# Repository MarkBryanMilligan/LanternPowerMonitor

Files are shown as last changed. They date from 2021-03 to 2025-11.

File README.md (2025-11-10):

# LanternPowerMonitor
The Lantern Power Monitor is a Raspberry Pi service, Java Web Service, and Android application that allow you to monitor every electrical breaker in your house, regardless of how many panels or breakers you have.
<br><br>
The official website has a lot of technical information:
<br>
[LanternPowerMonitor.com](https://lanternpowermonitor.com)
<br><br>
Here's an imgur album showing what this is and how it works:
<br>
[Lantern Power Monitor - Imgur](https://imgur.com/gallery/SPOJYBR)
<br><br>
The android application is available here:
<br>
[Lantern Power Monitor - Google Play](https://play.google.com/store/apps/details?id=com.lanternsoftware.lantern)
<br><br>
The iOS application is available here:
<br>
[Lantern Power Monitor - App Store](https://apps.apple.com/us/app/lantern-power-monitor/id1620735464)
<br><br>
The LanternPowerMonitor subreddit is a great place to ask questions and stay tuned for updates and news.
<br>
[/r/LanternPowerMonitor](https://www.reddit.com/r/LanternPowerMonitor/)
<br><br>

You can use the bom in the source below to buy the parts to build a hub.

# Index
## bom
An excel file that lists every part required to construct a Lantern Power Monitor Hub and links to where each part can be purchased.<br>

## case
STL files and Blender models to print your own case for a Lantern Power Monitor Hub
## java
Contains all source code for the raspberry pi service and the web service.  The raspberry-pi service posts data to the web service which also handles requests for data from the android app.
#### lantern-powermonitor
This is the raspberry pi service.
#### lantern-powermonitor-dataaccess
A mongodb implementation of the data access for the power monitor service.
#### lantern-powermonitor-datamodel
A shared data model used by the raspberry pi service, the web service, and the android application.
#### lantern-powermonitor-service
This is the web service (compiles to a war and can most easily be deployed to tomcat)
## lantern-util-*
Utility libraries used by the raspberry pi service, the web service, and the android application.
## lantern-zwave-*
These are only tangentially related.  These are libraries for running a zwave controller and a web service that the android app can use to control zwave devices and relays in your home.  This isn't currently part of the provided sd image, but I use it in my home to control our garage doors, compressors, lights, thermostats, thermometers, and all sorts of other fun stuff.
## pcb
Gerber files and the source EasyEDA file for the Lantern Power Monitor Hub v1 pcb.

# Ok, how do I run this thing?
The easiest way to run the software on a hub is to download a pre-built SD card image.  One can be downloaded here:<br>
[2.0.0.img.gz](https://lanternpowermonitor.com/images/2.0.0.img.gz)
<br><br>
Flash this to any micro sd card (4gig or larger) and you're good to go.  Fire up the hub and the phone app should be able to connect to it via bluetooth to finish the configuration.  The default password on this image is pi/LanternPowerMonitor<br><br>
When you add the hub to your configuration via the app, you can change where the hub posts data.  If you use lanternpowermonitor.com (the default host), your data will be stored there securely and won't be shared with or sold to anyone.  If you really want to run your own server, you're of course welcome to do that instead, instructions are located further down.

## Now that the service is running on the pi, how do I configure everything in the android app?
1. Create your panel in the "Configure Panels" page from the main menu. Before you have your hub connected, there will be no place to select a hub and port for each breaker. Don't worry, we'll get to that later.

1. With your hub plugged in and running for at least a minute, go into the "Configure Hubs" page from the main menu. In here you'll see a status of "Scanning for Hubs..." If you're in range of your hub and its service is running, the app should find it pretty quickly (less than 15 seconds). If this is the first hub you've added, it will prompt you for your wifi credentials. After that, it will send via bluetooth the hub index (so it knows which hub it is), host (so it knows where to post data), auth code (so it knows which account it is and can post data), the encrypted wifi credentials, and finally a command to reboot.

1. After your hub reboots, it should acquire an ip from your router, start the service, and try to start posting data. The hubs will try to auto-calibrate your voltage to 120V too, but if your AC/AC transformer is not plugged in, it will notice that and not try to auto-calibrate. It will continue to try to auto-calibrate each time you restart the hub until it does so succesfully.

1. Now that your hub is in the app, you need to go back into your panel and map each space to the port that you plugged the CT into. So say you put a CT on space 4, and you plugged that CT into port 7 on your hub, in your panel config, select space 4 and at the bottom, select hub 0 and port 7.

1. After you have your ports mapped, the hub does not currently pick up that change automatically. I will make it do that eventually, but for right now, you need to restart your hub one more time. (You can do this via bluetooth, but it's probably easier to just yank the power and plug it back in)

1. After that second restart, you should start seeing data. If you're not getting data in your app, the hub probably was not able to get a wifi connection. You can pull the last 10 lines of the log file and network details from the hub via bluetooth on the hub config page to troubleshoot.

# Ok, but I don't like doing things the easy way.
First, you and I will get along just fine.  Second, do a reactor build from the root folder:
```
~/LanternPowerMonitor/java$ gradlew clean build publishToMavenLocal
```
## raspberry pi service
The compiled service will be at LanternPowerMonitor/powermonitor/lantern-powermonitor/target/lantern-powermonitor.jar<br>
This is a shaded jar that contains all of the required components to function.  It must be copied to /opt/powermonitor on the pi.<br><br>

After that, you need to install pigpio:
```
sudo apt-get install pigpio
```
You also need to have java 1.8 or newer installed.
To install the power monitor service, use a service file like the one below:
```
[Unit]
Description=Power Monitor
After=syslog.target network-online.target
Wants=network-online.target

[Service]
Type=simple

User=root
Group=root

WorkingDirectory=/opt/powermonitor

ExecStart=/opt/java/bin/java -cp /opt/powermonitor/lantern-powermonitor.jar com.lanternsoftware.powermonitor.MonitorApp

[Install]
WantedBy=multi-user.target
```
You may need to change the path of your jdk, but lantern-powermonitor.jar must be installed at /opt/powermonitor<br>
Move your powermonitor.service file to /etc/systemd/system/ and enable the service
```
sudo mv powermonitor.service /etc/systemd/system/
sudo systemctl enable powermonitor
```
## web service
So you don't trust me with your data, eh?  No worries, I get it.  Here's how you run your own server.<br><br>
After your reactor build, the compiled war will be at LanternPowerMonitor/java/lantern-powermonitor-service/build/libs/lantern-powermonitor-service-2.x.x.war
That can be deployed to tomcat.  The 'host' parameter in the raspberry pi config.json file needs to point to wherever you deploy the service so your hubs post the data to your server instead of the official lantern software one.<br>
I'd recommend a valid dns entry and an ssl certificate, but, it's up to you, you're already knee deep in "I'll do what I want" territory here.<br><br>
Before you deploy it, you need to generate a config file that contains the mongodb credentials.<br>
There is a file at lantern-powermonitor-config/src/main/java/com/lanternsoftware/powermonitor/CreateMongoConfig.java that can do this for you.<br>
Place the generated config file in /opt/tomcat (which is where I have tomcat installed).  If you want it to be read from somewhere else, you can modify the paths in LanternFiles.java<br><br>
The last thing you need is a private aes key to encrypt user auth tokens.  One of those can be generated with CreateAuthKey.java.<br>
I realize these instructions aren't complete, but if you're going down this path, I suspect you sort of already know what you're doing, so hopefully that's enough to point you in the right direction.

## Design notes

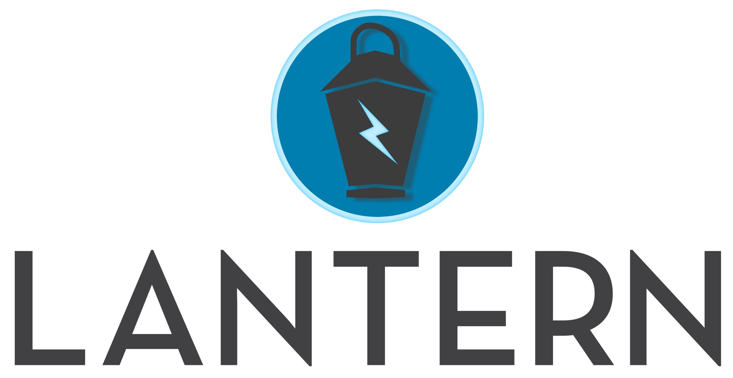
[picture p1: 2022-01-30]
java/lantern-powermonitor-service/src/main/webapp/img/lantern_cm.png

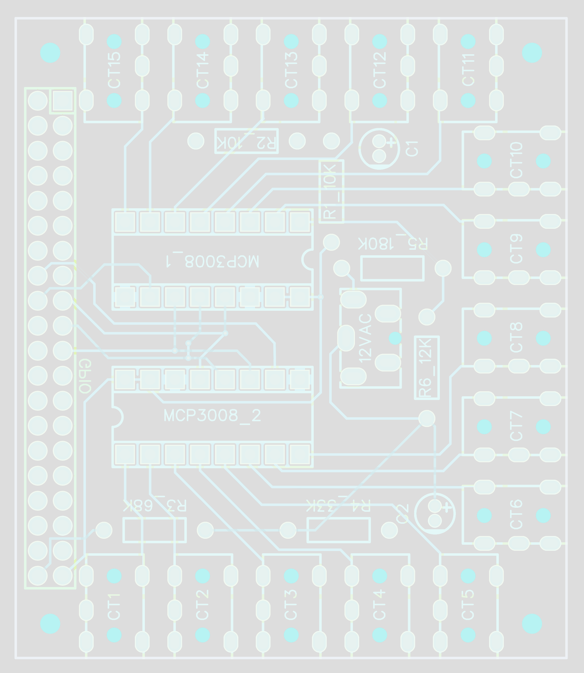
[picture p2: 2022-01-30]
java/lantern-powermonitor-service/src/main/webapp/img/pcb.png

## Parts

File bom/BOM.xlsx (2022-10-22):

Item Name | Part Number | URL | Quantity Required
Lantern Power Monitor Case | LPMC1 | https://github.com/MarkBryanMilligan/LanternPowerMonitor/tree/main/case | 1
Lantern Power Monitor Case Lid | LPMCL1 | https://github.com/MarkBryanMilligan/LanternPowerMonitor/tree/main/case | 1
Lantern Power Monitor Soldering Jig | LPMSJ1 | https://github.com/MarkBryanMilligan/LanternPowerMonitor/tree/main/case | 1
Lantern Power Monitor PCB | LPMPCB1 | https://github.com/MarkBryanMilligan/LanternPowerMonitor/tree/main/pcb | 1
Raspberry Pi 3 Model A+ | 3A+ | https://www.raspberrypi.org/products/raspberry-pi-3-model-a-plus/ | 1
Jameco 12V AC/AC Adapter | 10428 | https://www.jameco.com/z/ACU120100Z9121-Jameco-Reliapro-AC-to-AC-Wall-Adapter-Transformer-12-Volt-AC-1000mA-Black-Straight-3-5mm-Male-Plug_10428.html | 1
16gb memory card | P-SDU16GU185GW-GE | https://www.microcenter.com/product/486146/micro-center-16gb-microsdhc-class-10-flash-memory-card | 1
40-pin GPIO header | C169819 | https://lcsc.com/product-detail/Pin-Header-Female-Header_Ckmtw-Shenzhen-Cankemeng-C169819_C169819.html | 1
MCP3008 | MCP3008-I-P | https://www.digikey.com/en/products/detail/microchip-technology/MCP3008-I-P/319422 | 2
10uF 25V 4*5 Capacitor | C43846 | https://lcsc.com/product-detail/Aluminum-Electrolytic-Capacitors-Leaded_CX-Dongguan-Chengxing-Elec-10uF-25V-4-5_C43846.html | 1
22uF 25V 4*7 Capacitor | C43840 | https://lcsc.com/product-detail/Aluminum-Electrolytic-Capacitors-Leaded_CX-Dongguan-Chengxing-Elec-22uF-25V-4-7_C43840.html | 1
10KΩ Resistor | C385441 | https://lcsc.com/product-detail/Metal-Film-Resistor-TH_TyoHM-RN1-2WS10K%CE%A9FT-BA1_C385441.html | 2
12KΩ Resistor | C385449 | https://lcsc.com/product-detail/Metal-Film-Resistor-TH_TyoHM-RN1-2WS12K%CE%A9FT-BA1_C385449.html | 1
180KΩ Resistor | C385460 | https://lcsc.com/product-detail/Metal-Film-Resistor-TH_TyoHM-RN1-2WS180K%CE%A9FT-BA1_C385460.html | 1
33KΩ Resistor | C385498 | https://lcsc.com/product-detail/Metal-Film-Resistor-TH_TyoHM-RN1-2WS33K%CE%A9FT-BA1_C385498.html | 1
68KΩ Resistor | C433508 | https://lcsc.com/product-detail/Metal-Film-Resistor-TH_TyoHM-RN1-2WS68K%CE%A9FT-BA1_C385541.html | 1
3.5mm Headphone Jack | C397337 | https://lcsc.com/product-detail/Audio-Video-Connectors_XKB-Enterprise-PJ-3583-B_C397337.html | 16
M2.5x10mm Cap Screw | A15120300ux0225 | https://www.amazon.com/gp/product/B01B1OD7IK | 8
M2.5x11mm Female x Female Standoff |  | https://www.ebay.com/itm/50pcs-M2-5-Female-Hex-Screw-Brass-PCB-Standoffs-Hexagonal-Spacers/172746413434 | 4
M2.5x12mm Female x Male Standoff |  | https://www.ebay.com/itm/M2-5-2-5mm-Thread-6mm-Brass-Standoff-Spacer-Male-x-Female-20-50pcs-New/283432513974 | 4
50 Amp Current Transformer | SCT-013-050 | N/A
30 Amp Current Transformer | SCT-013-030 | N/A
20 Amp Current Transformer | SCT-013-020 | N/A

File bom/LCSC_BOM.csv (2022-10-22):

LCSC Part Number | Quantity
C2977589 | 1
C43846 | 1
C43840 | 1
C385441 | 2
C385449 | 1
C385460 | 1
C385498 | 1
C433508 | 1
C397337 | 16

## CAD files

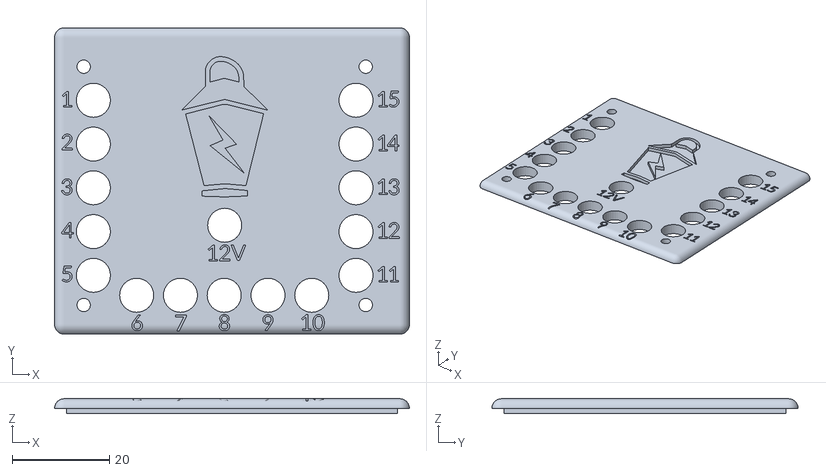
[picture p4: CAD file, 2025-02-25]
case/3A+/LPM_Case_Lid_3A+.stl
73.0 x 63.0 x 3.00

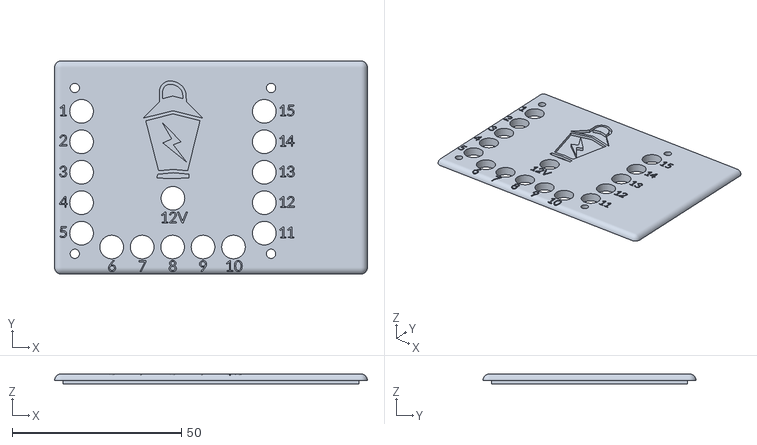
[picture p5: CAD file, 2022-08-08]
case/3B+/LPM_Case_Lid_3B+.stl
92.5 x 63.0 x 3.00

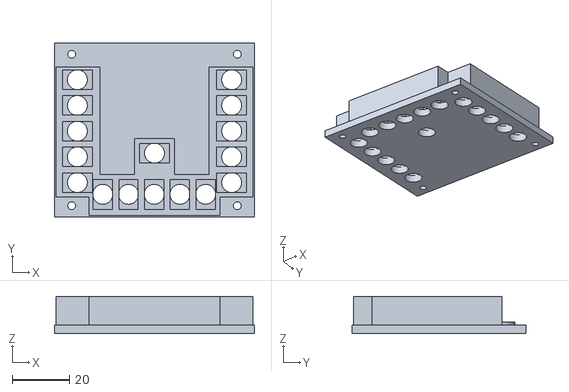
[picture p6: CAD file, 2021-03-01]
case/LPM_Soldering_Jig.stl
70.0 x 61.0 x 13.0

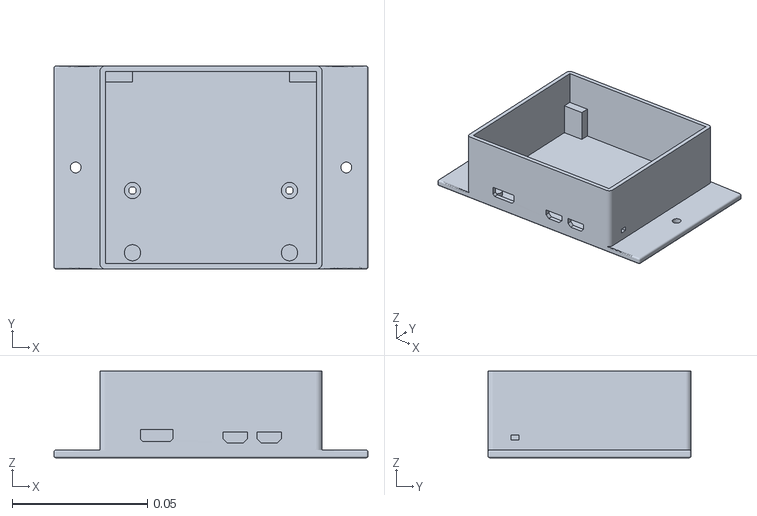
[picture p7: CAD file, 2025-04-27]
case/Z2/LPM30_Case_Z2_Base_Flange.stl
0.116 x 0.075 x 0.032

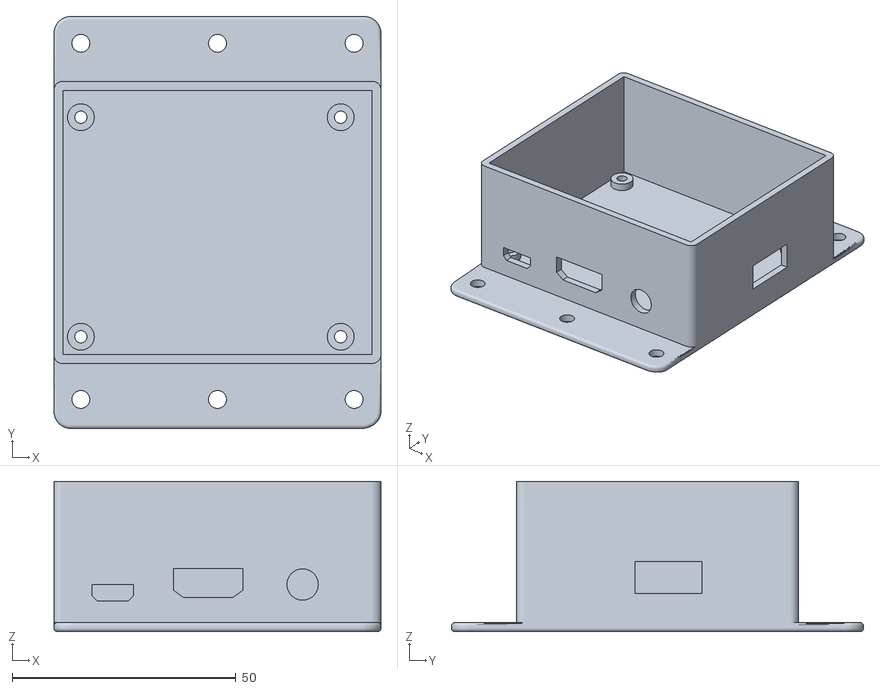
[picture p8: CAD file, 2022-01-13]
case/3A+/LPM_Case_Flange_3A+.stl
73.0 x 92.0 x 33.5

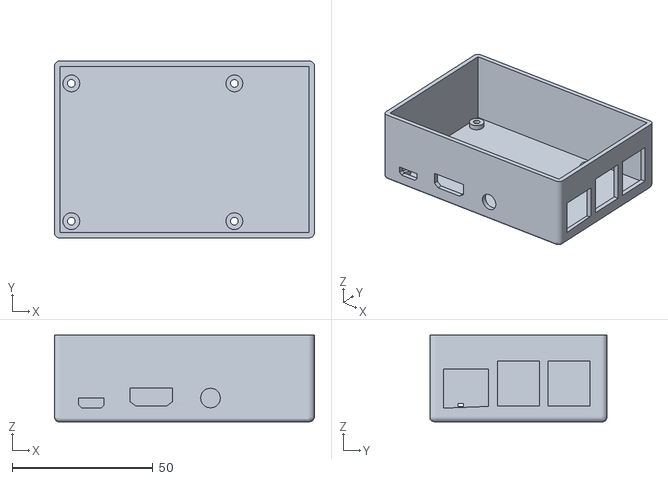
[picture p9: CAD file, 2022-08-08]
case/3B+/LPM_Case_3B+.stl
92.5 x 63.0 x 30.9

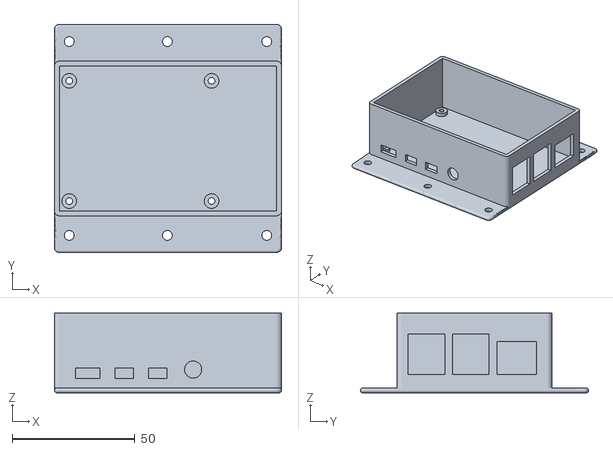
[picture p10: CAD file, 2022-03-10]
case/4B/LPM_Case_Flange_4B.stl
92.5 x 93.0 x 32.5

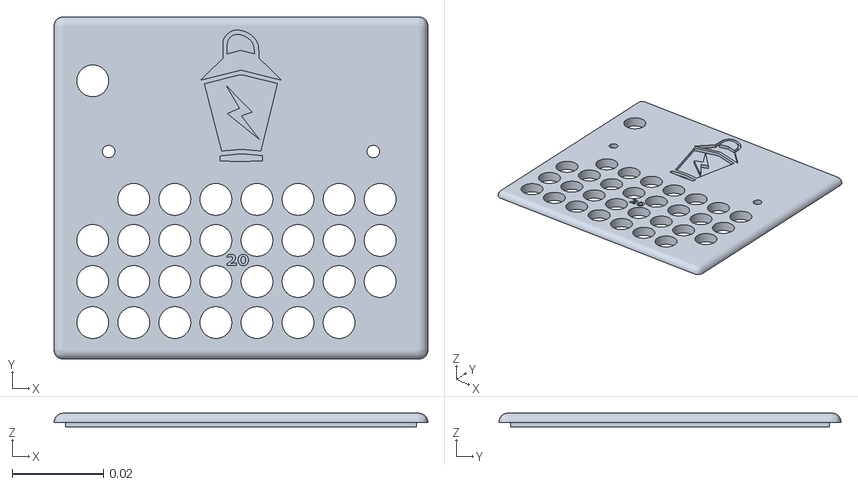
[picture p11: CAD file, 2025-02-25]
case/Z2/LPM30_Z2_Text_Lid.stl
0.082 x 0.075 x 0.003

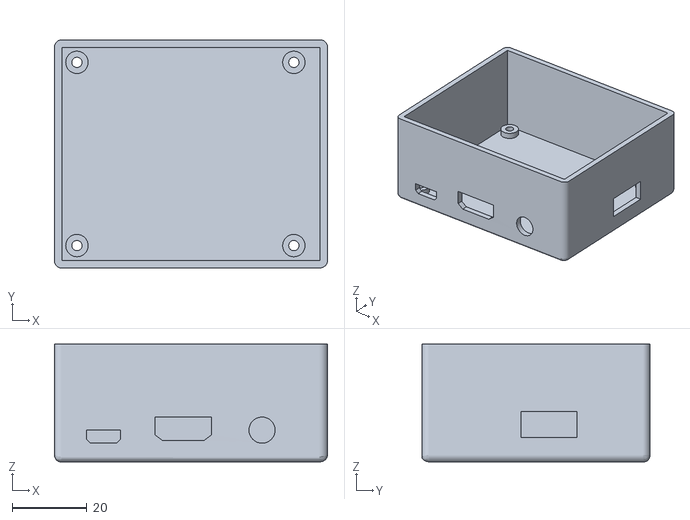
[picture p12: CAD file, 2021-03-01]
case/3A+/LPM_Case_3A+.stl
73.0 x 61.0 x 31.5

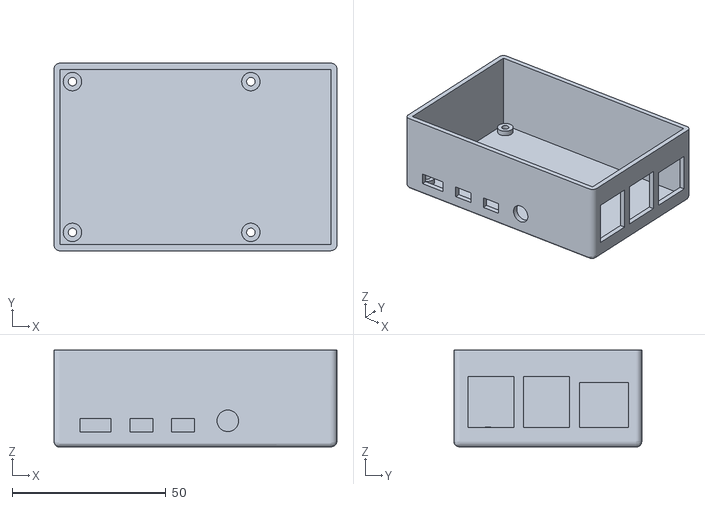
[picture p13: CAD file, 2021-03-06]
case/4B/LPM_Case_4B.stl
92.0 x 61.0 x 31.5

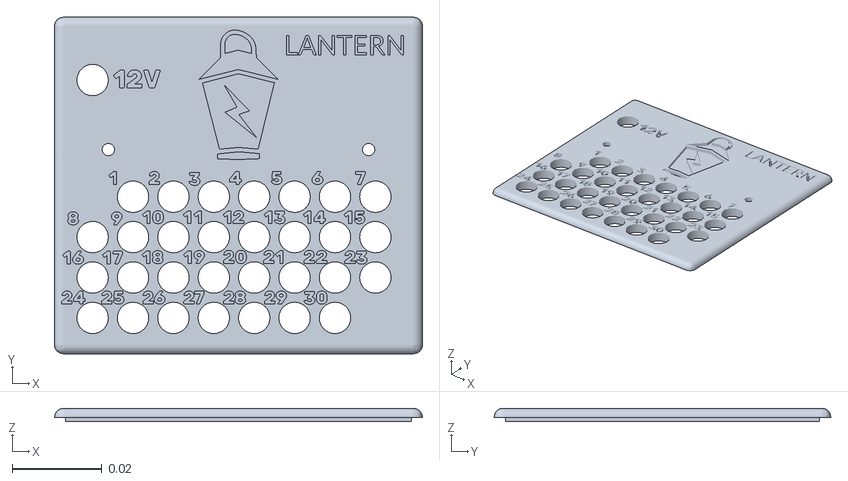
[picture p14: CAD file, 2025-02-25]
case/Z2/LPM30_Z2_Lid_Labeled.stl
0.082 x 0.075 x 0.003

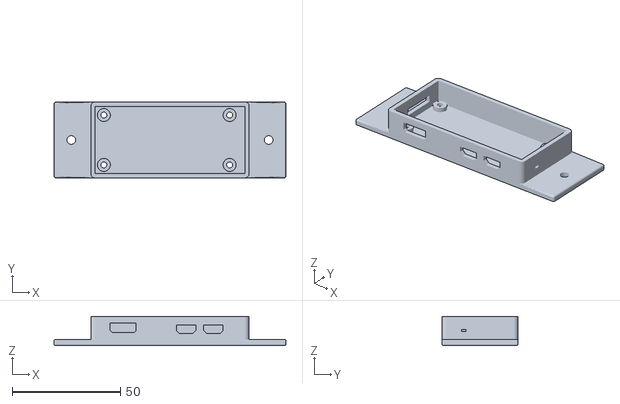
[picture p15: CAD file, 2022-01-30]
case/Z2/LPM_Case_Z2_Base_Flange.stl
107.0 x 35.0 x 13.5

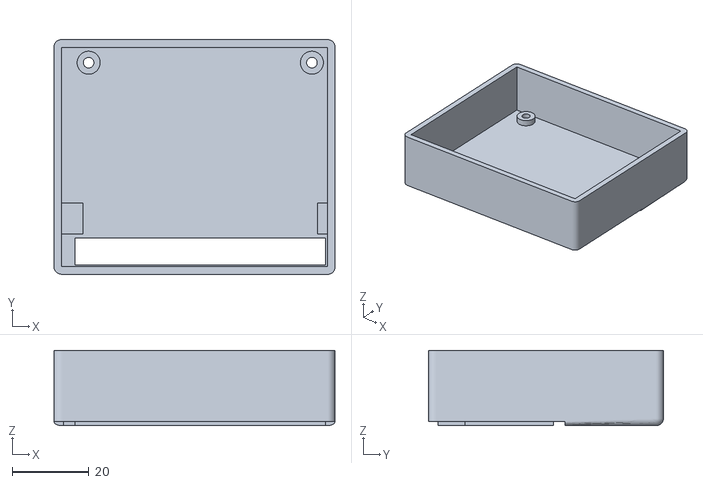
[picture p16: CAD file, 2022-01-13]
case/Z2/LPM_Case_Z2_Middle.stl
73.0 x 61.0 x 19.5

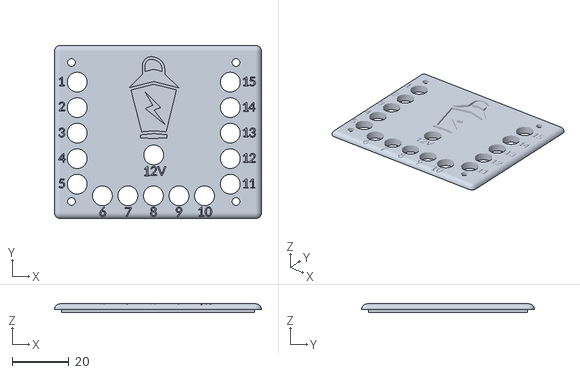
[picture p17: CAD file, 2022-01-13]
case/Z2/LPM_Case_Z2_Lid.stl
73.0 x 61.0 x 3.00

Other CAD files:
case/4B/LPM_Case_Lid_4B.stl
case/3B+/LPM_Case_Flange_3B+.stl
case/Z2/LPM30_Case_Z2_Lid.stl
case/Z2/LPM_Case_Z2_Base.stl
case/3A+/LPM_Case_3A+.blend
case/3A+/LPM_Case_Flange_3A+.blend
case/3A+/LPM_Case_Lid_3A+.blend
case/3B+/LPM_Case_3B+.blend
case/3B+/LPM_Case_Flange_3B+.blend
case/3B+/LPM_Case_Lid_3B+.blend
case/4B/LPM_Case_4B.blend
case/4B/LPM_Case_Flange_4B.blend
case/4B/LPM_Case_Lid_4B.blend
case/LPM_Soldering_Jig.blend
case/Z2/LPM30_Case_Z2_Base_Flange.blend
case/Z2/LPM30_Case_Z2_Lid.blend
case/Z2/LPM30_Case_Z2_Lid_Labeled.blend
case/Z2/LPM30_Case_Z2_Lid_text.blend
case/Z2/LPM_Case_Z2_Base.blend
case/Z2/LPM_Case_Z2_Base_Flange.blend
case/Z2/LPM_Case_Z2_Lid.blend
case/Z2/LPM_Case_Z2_Middle.blend
case/Z2/Z2_GPIO_Lid.blend
case/Z2/Z2_GPIO_Lid.stl
case/logo.blend

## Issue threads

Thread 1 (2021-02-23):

Track 240V double breaker with one CT

MarkBryanMilligan, 2021-02-23:
Right now, each pole of a double pole breaker requires its own CT.  To save on the cost of current transformers, add a configuration variable so only the top breaker needs a CT and the power of the top pole is doubled in software.

JamesAndrews352, 2021-02-23:
That would save some hardware for sure. Keep in mind some 240v loads may have a neutral and 120v loads like a stove/range, but yeah, most are balanced. I have a 30 space panel with 1 tandem breaker, so I like the idea. Save me from a third meter. Love your work!!

MarkBryanMilligan, 2021-02-23:
Ok, thanks for that info.  That's why I decided to track both for now just to make sure it was accurate, I had a feeling some appliances might have unbalanced usage.  None of mine do, but it's good to know that it's a possible use case.  I think I'll make this a configuration option for the double breaker so those who need to track both poles individually will still be able to.

dcsar1, 2021-02-23:
Another vote for this one.  I just ordered a couple of kits.  When the canoe from China (with the sensors) finally makes landfall I hope to set this up.

MarkBryanMilligan, 2021-02-23:
It's kinda lame that GitHub doesn't have a voting system for issues.  What could that take to add, like an afternoon??  I always add a comment when adding an issue (and I would expect anyone else creating an issue to do the same).  I think we should use a thumbs up on that first description comment to count as a vote.  Then I should be able to visualize a little more easily what to do first.

MarkBryanMilligan, 2021-02-26:
Ok, this one is done:
[Commit](https://github.com/MarkBryanMilligan/LanternPowerMonitor/commit/a75231dc437cc4e1e5b87e6aec084bac215a0ebe)

I'll leave this issue open until someone else verifies that it works, but I just tried it in my house on our heat pump and it seems to be working fine.  I'll push a new release to google play for the app, it should be available tomorrow.

In the panel config, you can now select "Double Pole (240V) Two CTs" or "Double Pole (240V) One CT Doubled"

MarkBryanMilligan, 2021-02-28:
I saw when I close the other issue that I can reopen them if there ends up being a problem.  This change has been working fine in my has for the past couple days so I'm gonna go ahead and close the issue.

Closed 2021-02-28.

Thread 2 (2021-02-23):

Allow tracking mains power in addition to individual breakers

MarkBryanMilligan, 2021-02-23:

kitlaan, 2021-12-26:
I noticed there is no 200A CT available in the 0-1V configuration. Does that put a limit to this feature?

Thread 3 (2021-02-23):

Create Raspberry Pi 4 image

MarkBryanMilligan, 2021-02-23:
The current image only seems to work on a Pi 3 out of the box.  It can be made to work on the Pi 4 but you need to tweak some stuff on the command line.  It'd be easier for Pi 4 users to have an image that works without any modification.

rharter, 2021-02-23:
Curious if there's any reason this can't work on a Zero.  The Zero W has a 40 pin header (no stock connector), and seems comparably speced to the 3A. And...it's $10. Event better, the original Zero 1.3 is $5 at [Adafruit](https://www.adafruit.com/product/2885), which is really attractive for something like this, which doesn't need USB hubs and HDMI ports.

MarkBryanMilligan, 2021-02-23:
I kind of expect it to be CPU limited.  On a pi 3 A+ (or B+) with the quad core Cortex-A53 1.4 GHz, it gets about 300 samples per cycle.  On a 4 b+ with its quad core Cortex-A72 1.5 GHz, it gets about 400 samples per cycle.  A zero only has a single core and I keep one core pegged at 100% cpu 24/7 sampling the ADCs.  I thread off calculating the power and posting it to the server since there are other cores available for that work.  I have a feeling on a single core machine running java, the sampling would get all jacked up as garbage collection occurs during the computation and http call phase of each second.

MarkBryanMilligan, 2021-02-28:
I made a new image that works on both pi 3s and pi 4s.  I also zipped it this time to make the download smaller.  The new image is [here](https://lanternsoftware.com:13781/hub_1.0.0.zip)

Closing this issue.

Closed 2021-02-28.

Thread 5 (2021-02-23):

Allow configuration of non-US systems

MarkBryanMilligan, 2021-02-23:
Right now the app assumes 60Hz 120V.  The data model, hubs, and server support other frequencies and voltages, but there's no place to set them in the app.  Once I add a meter page, this should go there.

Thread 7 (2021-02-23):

Get the Android code posted to GitHub.

MarkBryanMilligan, 2021-02-23:
I need to externalize some secrets from the app before I post it to GitHub.  There's also a whole other half of the app for controlling z-wave devices and reading usb thermometers that really only works for my house right now.  That other half of the app is just turned off unless you set the host to the server at my house here.  I need to get that cleaned up before I post the code so people don't start turning my lights on and off and hotboxing my family in the middle of the night.

phinze, 2022-03-19:
Hi @MarkBryanMilligan! My power monitor is arrived and physically installed, but it was only at that point that I realized that I don't have any Android devices handy outside of an old TV remote (Vizio XR6M10). Unfortunately this device is stuck on Marshmallow which won't install the app from the Play store. I was wondering if that minimum Android version constraint was something that could be easily tweaked, which brought me here. I'd be happy to take a look at this myself if you can push the code.

Ultimately though I'm going to be more interested in the iOS platform, so I'd love to hear any update on where things are at on that front. Regardless, I'm excited to chip in a bit and get things cooking w/ my monitor! :)

MarkBryanMilligan, 2022-03-19:
The minimum is Android 7.1 because Android made a huge non-passive change to the way the bluetooth platform works on that version.  Making bluetooth work on an older version of Android would be a ton of work and I'd rather spend that time on iOS.

If you feel like a project, you could root your Vizio tablet and install LineageOS on it.  I did that with my 10 year old Nexus 7 tablet and it works great with the app now.  A quick google search for "Vizio XR6M10 LineageOS" can probably get you started (again, at your own risk, legality and safety not guaranteed :) )

I'm back to working on the iOS app.  I have the data rendering in the graphs ok, but I need to do all of the configuration pages and the bluetooth stuff.  It's at least a couple months of work.  I'm developing on a 2012 Mac Mini right now and it's crazy slow.  I finished shipping out all of the Kickstarter rewards this past week (except for those who haven't responded to my survey), so I need to double check how much money is left from the Kickstarter.  If I have enough I want to get a new M1 Mac Mini to speed up the iOS development.

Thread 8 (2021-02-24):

Add "Sense" like capability per circuit

JamesAndrews352, 2021-02-24:
While most loads are obvious, for example, the water heater is the only load on the water heater breaker. A kitchen may have a dishwasher, microwave, and garbage disposal on the same circuit. I'm not proposing some fancy artificial Intelligence, just the ability to turn on an appliance and have the system recognize that specific load, then it would be broken out under that circuit so you know how much each appliance uses. Maybe more complicated than I think.

MarkBryanMilligan, 2021-02-24:
Yeah, I could see the use for an intermediate mode, not really what sense does.  So like you just manually figure out what each device uses by watching the instantaneous power while you turn it on and off.  Oh, ok, my microwave uses 1300 watts.  Now I'll configure a watch item for this breaker, if the power jumps between 1200 and 1400 up or down, well then that's the microwave turning on or off.  Basically manually train it for each thing.  Then you add in some extra logic in the summary aggregation that watches for those changes and puts the power in a subgroup when the state changes.  I bet that's about a week project.

kitlaan, 2021-12-26:
I ran across the [NILMTK](https://github.com/nilmtk/nilmtk) while googling around, which seems to be research around this area.  It's all voodoo to me so maybe someone else can determine what's required to utilize it.

At the very least, a way to store/export data in HDF5 format may be useful to help the community and/or allow external integrations?  (Aside, the data storage requirement is probably high, so storing on a SD card seems unwise? USB storage? NAS?)

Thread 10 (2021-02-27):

Modify the case for the pi 3A+ to have mounting tabs

MarkBryanMilligan, 2021-02-27:
The current case can only rest on something.  There needs to be a version of it with tabs on the side with holes that a screw could be put through for wall mounting.

JamesAndrews352, 2021-02-28:
I like that the case is so small, but I can see where some may want to screw it to something. Since it will have to be raised to clear the screw heads, It will require support while printing. Probably easiest solution is make the bottom thicker with the added material extending past the ends and recess the screws. I'll look at it.

JamesAndrews352, 2021-02-28:
I have a revised box with flange but don't know how to upload it

JamesAndrews352, 2021-03-01:
You can view it on my google drive. I re scaled the other files as well so they should print. Let me know if you hate it or want to change something. I put the flange on the long side since you have to have power plugged in the one long side anyway.

https://drive.google.com/drive/folders/1ZbKBfhDIAYEkUGRTl0iSNntp58AsMB6w?usp=sharing

MarkBryanMilligan, 2021-03-01:
All of the scaled ones look great!  Thanks for fixing that for me.  How did you re-scale them?
I'm only seeing one issue with the flange case, it looks like one of the vertices from the standoffs on the bottom of the case got connected to the side wall.  At least that's the way it looks when I import into cura.  I haven't tried printing it yet though, so I don't know if it's actually a problem.  [Here's a picture](https://lanternsoftware.com:13781/artifact.png)

JamesAndrews352, 2021-03-01:
I found that I could export the STL from prusa slicer after scaling it. I'm not sure what you are seeing on the flanged one. I just uploaded a different version. Flange still looks too big but I got rid of some gaps.

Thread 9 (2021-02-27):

Create a case stl for the pi 4.

MarkBryanMilligan, 2021-02-27:
The current case for the 3A+ needs to be modified in blender to be longer and have room for all the ports of a pi 4.  Probably about a day's work.

MarkBryanMilligan, 2021-03-06:
Case created and added [here](https://github.com/MarkBryanMilligan/LanternPowerMonitor/commit/181513c06db10dbfeb13d4c993a0af13e668741f)

Closed 2021-03-06.

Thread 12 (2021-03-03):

New software

desperateone, 2021-03-03:
Your new software was updated today on my phone so I went to redo the double pole breakers. Before that I'm currently showing a need of 16 CT's. Which is for 240V double-poles, 2 tandem breakers and four singles. After redoing and selecting " Double Pole (240V) One CT Doubled " for the four 240V breakers. I'm still showing 16 brekers and a BOM still shows 16 breakers where I'm expecting it to now show 12 breakers and BOM of 12 CT's but it as if it hasn't changed, am I doing something wrong ? Or is it a bug ?

MarkBryanMilligan, 2021-03-03:
Yeah, that's totally a bug.  I changed the software so the hubs would use the config to double the power for a single pole of a double breaker, but I haven't updated the BOM generation.  I'll fix that here and have a release out in a few hours.  Regardless of what the BOM generation does, the hubs will work just fine with one CT on a double pole if you configure it that way.

MarkBryanMilligan, 2021-03-03:
I thought you had already ordered your CTs.  You made a rather threatening complaint a few days ago about how much you had spent on CTs.  Does this bug actually affect you in any way?

MarkBryanMilligan, 2021-03-03:
I deployed a fix for this, it's live now.  Good luck.

desperateone, 2021-03-03:
> I thought you had already ordered your CTs. You made a rather threatening complaint a few days ago about how much you had spent on CTs. Does this bug actually affect you in any way?

CT's coming from China, should be here by March 15th

Closed 2021-03-03.

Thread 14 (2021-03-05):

[Android APP] - Add a 'shutdown' button

jeremyparks, 2021-03-05:
I noticed when moving my pi there was no button to shut down.  It is better to shut down than just pull the plug to avoid data corruption.

MarkBryanMilligan, 2021-03-06:
Just to clarify, you're saying add this as an action button on the hub page, so the phone can instruct the hub to shut down via bluetooth?  That shouldn't be too hard to add, I just want to make sure I have the workflow right.  I was thinking about maybe allowing the hubs to be pull commands from the service as it posts its data.  It'd be a little faster and less clunky than bluetooth, but I haven't built the framework for it yet.

jeremyparks, 2021-03-06:
Yeah, got the idea from Octoprint. You can shutdown the pi from the
interface. Since the pi runs as headless it is nice to have the option to
shutdown (poweroff).

It would be similar to reboot that you already have.

On Fri, Mar 5, 2021, 5:27 PM MarkBryanMilligan <notifications@github.com>
wrote:

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

MarkBryanMilligan, 2021-03-07:
This is done.  Android app is released, hub software needs to be updated to 1.0.2 for it to work.  [Commit](https://github.com/MarkBryanMilligan/LanternPowerMonitor/commit/2a5674b736db4ad590bddd8b8e3cf99d29c3e48e)

Closed 2021-03-07.

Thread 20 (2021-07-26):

Feature Request: Add price per kilowatt conversion factor and toggle to see usage in dollars and cents.

dev464, 2021-07-26:
So I keep looking at my kilowatt readouts and doing the conversion on my phone or in my head to see how much I'm actually spending for certain appliances. It'd be cool if this was integrated. To be able to enter my price per kilowatt on the app and then just touch the total usage box and see it in dollars. Then when I drop down the breakers see totals in dollars and then the livestream value could be configurable between cents/dollars, and then per time unit minute/hour/day/week/month/year. Maybe even on the graph too. Not a vital feature by any stretch but I think it'd be useful.

MarkBryanMilligan, 2021-07-26:
I've been meaning to add this for a while and here are a few things to consider, would love to have your input.

I'm thinking of setting this value per meter.  99% of people only have one meter and in that case I can just hide the complexity of it and you only set one value.  But in my house, we have two meters, one for heat and one for everything else and both meters charge at different rates.  To further complicate it, our power company charges tiered rates, first 400kWh are one rate, then the next 600kWh at another rate, and then everything over 1000kWh are a final rate.  Then, the rate changes twice per year for the transition from heating to cooling.

That's why I've been procrastinating on this feature.  My power company is insane and the rules are obscenely complicated.  Trying to create a data model that can accommodate the billing systems of every electricity provider on earth has me a little bit scared.

For the short term, should I just put in an "average rate" value to keep it simple and provide a ballpark estimate, or should I tackle the more complicated scenarios up-front?

dcsar1, 2021-07-26:
I think you could start with an average rate as that would be immensely easier to code and be generally useful to everyone.  Getting into the complicated mess of variable rates will likely be a significant effort and you will always be behind as the insane folks at the various power companies keep coming up with even crazier ways to get more of your money and make you grateful to give it to them...  We are flat rate currently but that will soon change to rates based on time-of-day.

dev464, 2021-07-30:
So I'd say its totally up to you what you want to do first. I've got thoughts on how to accomplish the complex task though so I'm just gonna go ahead at this moment and do a brain dump... Let me know what you think.

[https://imgur.com/a/ItNCxQn](https://imgur.com/a/ItNCxQn)

So first off, regardless of how complex or simple these rules get, I know you mention that some companies change their rates year by year or season by season, so if we don't want these seasonal or annual changes to affect previous totals or readings we will need to bake something in that allows us to freeze or lock in dollar values for certain readings or time periods. I'm assuming you're storing all values in some kind of database and that there's maybe 2 data sets side by side, one that stores Watts at the point of the reading and then another that totals the assumed total usage between two point values. I'm also assuming it makes more sense to store one value for this dollar value and if the user ever wants to see it in cents per second or dollars per hour or however they want to see it, to have their phone just run the conversion and trade slightly higher user processing for more efficient storage. But from there we only need 2 db fields then, total in cents, and value freeze/lock.
So as you set up your rules on the app they're only ever looking at existing kWatt totals and applying rules to unfrozen values writing into one field according to those rules. Also rules would be applied to entries in these fields (when being applied retroactively to unfrozen values) that are in specified date/time ranges as defined in the rules. Any time you go to change rules maybe the app asks the user if they'd like to freeze all values in the past to avoid changing good data. Here is a quick screen I shopped up to show something that might capture some necessary functions. This is by no means comprehensive, so take it with a grain of salt. My boss just happened to be out sick today and there was nothing to do at work lmao. Some of the features I was building in my head kind of got away from me a bit as I was photoshopping the screen. Not exaaaactly sure how some of these features would jive together exactly but figured it might help to get the juices flowing. Looking back at it probably don't have a need for those radio buttons with single vs multi rule and rate modes since you can always just have multi enabled and only input a single rule or rate. Thinking maybe the complicated part will be whether the rules will pivot off of date ranges or time ranges if companies actually change rates based on time of day. Maybe this deserves a radio button option that changes the scheduler mode. Not sure. Also these buttons on the bottom kinda clash with the scheduler concept a bit. Maybe there should just be a separate screen that allows you to lock or freeze specific date ranges so no matter what you do with any new rules, older proven values cannot be affected. Eh I dunno.  Sorry for the rambling stream of consciousness here lol.

MarkBryanMilligan, 2021-07-30:
Making the UI simple enough to be usable while complex enough to accommodate all of the billing scenarios is definitely the most difficult part.  I appreciate the mockup, I'll use that input when I get around to arranging the config UI in the app.

The data model for the billing rates isn't too terrible, right now the most difficult aspect will be applying it to the raw power readings.  Because solar production into the grid can pay at a different rate than grid consumption, I need to apply that billing rate per second, which is the smallest interval that gets sent to the server.  Aggregation into summaries is done server side as data is posted, and the summaries that are sent to the phone only contain data per minute.  This is for performance reasons as I can build the data summaries in a few milliseconds server side, but to send the raw per second data to the app, the data can be quite large. (86400 seconds per day, 4 bytes per sample, maybe 50 breakers ≈ 17MB.)

Since it can be cloudy for the first half of a minute and you may turn on your AC in the second half, the per minute data that gets sent to the app won't be detailed enough to apply accurate billing on the client side.  That's really a shame too because, for scalability reasons, it would be ideal to apply that on the phone side.  But I can't really have the phones downloading 17MB of data every time the app loads.

For solar, I'm already calculating the "from grid", "to grid" data and I do it at the second level when I'm building the summary aggregations.  So, I just need to enhance that a little bit and do it at a per breaker level and apply the billing rate at the same time and store it all separately in the summary model.  Not insurmountable, but a little more complicated than you would expect at first glance.

MarkBryanMilligan, 2021-08-04:
I went ahead and handled all the super-complicated cases.  You can define time of use, kwh thresholds, and production vs consumption rates.  All the rates can be defined per meter.  The data model for the config is [here](https://github.com/MarkBryanMilligan/LanternPowerMonitor/blob/main/currentmonitor/lantern-datamodel-currentmonitor/src/main/java/com/lanternsoftware/datamodel/curren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)  The server calculates the rate in real-time as power gets pushed to the server so you can see it in the app each minute as it reloads.

Here's a [screenshot](https://lanternsoftware.com:13781/charges_in_app.png) of what it looks like in app that I just released to google play.  The graph is still just the kwh, but I'd like to eventually make that a cumulative graph of the charges.

I haven't added the UI to the app for building the config yet.  If you want to let me know the details of your rates (via e-mail/subreddit/here) then I can throw it in the database so you can use the app immediately and I'll get around to doing the UI for the config a little later.  I'll leave this issue open until I get the app totally done.

MarkBryanMilligan, 2021-08-11:
I released a new version of the app that allows billing rate configuration.  It will be available on google play after it gets through the review process (probably later today).

When you change your billing rates, all affected totals are recalculated and will be available in the app after the server finishes recalculating (might take a couple minutes).

Closing issue.

zyphlar, 2022-04-02:
I've just done my setup and am getting graphs, but I entered a price into the app and it says it's recalculating and yet no pricing information appears. It's as if the pricing feature doesn't exist outside of the billing rate configuration form, and doesn't match the screenshots. Maybe I have to wait for a few days to collect more data?

MarkBryanMilligan, 2022-04-02:
You might double check the "from" date on your billing rates.  I think it defaults to the current time, so if you're looking back at past data, the rate wouldn't apply.  You can go back in and move the from date earlier to have it apply to old data.

If that doesn't help, e-mail your username to me at mark.milligan@lanternsoftware.com and I'll take a look in the database and see what's going on.

Also, originally, you could only set billing rates, but I added an enhancement to allow multiple billing plans (which are just a grouping of rates), so you can compare all of the different plans that your power company offers.  Since I made that enhancement, I haven't gone back and updated the screenshots on the website.  I'll get to that eventually.

MarkBryanMilligan, 2022-04-02:
Ok, turns out this was a bug in the android app.  After I migrated from billing rates to billing plans, the app was still using the existence of the old billing rates to show the currency button on the main page.  Since my account had some old vestigial rates in my config, the button was displaying, but wouldn't for anyone else who added plans from the start.

Thanks for finding this bug!  I'm sure it's been affecting pretty much everyone.  I released a new version of the app, 1.0.23.  It's in review now and should be available within the hour.

zyphlar, 2022-04-02:
Thanks so much! Love this project and have been daydreaming enhancements to contribute since I installed it

Closed 2021-08-11.

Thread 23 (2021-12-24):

Multiple SPI buses?

kitlaan, 2021-12-24:
(Do you want to turn on Discussions, to not clutter up Issues?)

Disclaimer: I'm brand new to this equipment, so take this with a dish of salt...

I was reading some of the posts about your design, and noticed your statement about pegging a single core.  Since you have two MCP3008 chips (on the same SPI, and select between the two), this means you sample each round-robin.

Since Raspberry Pis have (at least) two SPI buses, have you thought about putting each MCP3008 on an independent bus, and thus read them simultaneously with two threads?

And then extrapolating from there, could you piggyback two PCBs to a single RasPi (and thus get 16x2 CTs hooked up, at your currently designed sampling rate)?

Alternatively, it looks like the RasPi4 has even more SPI buses (looks like 4 are feasible), so you could possibly read four MCP3008s simultaneously (at the cost of maxing out all the pi's cores...).

MarkBryanMilligan, 2021-12-24:
Yeah, I'll turn on discussions after this kickstarter is finished.  Multithreading and increasing the sample rate is definitely something I've considered.  The accuracy is so good with what I'm doing now I didn't feel like adding complexity to improve it further.  I'd be more interested in adding complexity if it meant being able to add more MCP3008s.  How would you wire up 4 chips to one pi?

kitlaan, 2021-12-24:
Here's my theory...

Use HSPI + 2 CS as you have currently.  Use VSPI + 2 CS for a second board.
I imagine running two threads concurrently each running its own SPI could get you the current accuracy, but now with double the number of CTs (semaphores notwithstanding).

Assuming that even works, I wonder if you can split the AC transformer to both boards...

I guess the simplest experiment (once I get boards) is rather than stacking the PCB to the pi directly, just wire them up manually, each to its own SPI.

MarkBryanMilligan, 2021-12-24:
I need to look into how to access SPI1.  I'm using wiringPi for all of this interaction and the guy who maintains that rage quit a while ago, and I'm not sure if it provides access to SPI1.  Maybe there's a newer library I should be using.

If it's really possible to do that, I would just redesign the board to put it all in one, and then I only need to use one port for the voltage, and 31 for current.  That would be pretty amazing.  Even a pi zero 2 w has plenty of cpu room to double the ports.

kitlaan, 2021-12-24:
Here's what I ran across this during the googling-fest in the last hour...
* WiringPi seems to only support SPI0.
* http://abyz.me.uk/rpi/pigpio/index.html; looks like there are java bindings
* I'm curious what the performance difference is if you accessed via sysfs: https://jumpnowtek.com/rpi/Using-mcp3008-ADCs-with-Raspberry-Pis.html

MarkBryanMilligan, 2021-12-24:
I really need to rewrite the pi code in C.  It'd be so much faster and I'd have so much control over memory.  I went with java so I could use the same data model on the pi, the server, and the android app.  I pre-allocate all the memory for the SPI reads in java so garbage collection isn't triggered, but it'd be more deterministic in C.  To really optimize I probably need to switch to C.  JNI works and all, but man I hate it.  Why are you throwing all of these good ideas out here on the most stressful night I can remember waiting for a kickstarter to hit its goal!?!?

kitlaan, 2021-12-24:
Sorry; I only started digging because there's only hours left and I'm itching to poke around. 😀
I wish I had run across this project months ago...

I'd be pretty happy if you switched to C/C++ as I could help with development (as my Java's pretty much completely been paged out in the last two decades).

MarkBryanMilligan, 2021-12-24:
Let's see how tonight goes.  Regardless of whether the kickstarter succeeds or fails, I want to optimize the pi.  If we could get 31 breakers on one pi, it would crush anything else out there.

kitlaan, 2021-12-24:
Since I can't leave well enough alone (and I don't know how to turn off my brain on PTO)... I was pondering how you could have a single PCB module supply 16 plugs but allow them to be multipurpose.

Some half-baked thoughts:
* a single PCB design that allows the voltage jack to be dual duty, so you can have 15+1 or 16 CT
* ... by keeping the voltage divider circuit but changing the connection via a jumper/solderbridge
* ... by not populating the voltage divider circuit at all and solder-bridge
* keep the existing 40-pin header -- for 1xPCB usage
* ... option of stacking header and solder-bridge/cut to switch the SPI used
* ... or a 2-4 way adaptor board that routes each set of "6 SPI0 pins" to the proper raspi pins

aka, you could have a single board made (thus not needing to keep track of different SKUs) that folks can buy in the multiples they need instead of a single big board that costs a lot.  (I'm handwaving that "doubling" the board components basically doubles the cost.)

Since the voltage divider circuit cost isn't huge, If you just have the board maker populate everything (instead of two runs of with and without), that keeps to one board (again, SKU management).

The 40-pin header cost adds up (annoyingly) and is a waste of pins.  SPI0 uses a block of 2x4 pins, so maybe saving you the few cents there gives you the funds for stocking some adaptor boards.

As for the adaptor board... depending on how you lay out the connector pins, the case could be (raspi 4 w/ four boards = 63 breakers) 4x the width of your current one (and lots of empty standoff space), or 2x2.   If for other raspis, 2x width (31 breakers).

Or I'm just overthinking this and have folks solder wires to a header and its a little messier.

Either way, making it modular also makes the configuration a LOT more complicated, but it doesn't change the complexity of the "single PCB case" (assuming you hide the modular mechanism behind a toggle/button).

kitlaan, 2021-12-24:
And so I don't lose it in all my tabs...

* [Raspi4 SPI0/1 vs SPI3/4/5/6](https://forums.raspberrypi.com/viewtopic.php?t=246792#p1576629)
* [Raspi4 pinout](https://blog.stabel.family/raspberry-pi-4-multiple-spis-and-the-device-tree/)

TL;DR -- if someone wants to use Raspi4 3-4x SPI (aka 32-63 breakers) they need to use a different pinout than the Raspi3/zero2/Raspi4 1-2x SPI (1-31 breakers) configuration.

4 | SPI |   | 2 | SPI
-- | -- | -- | -- | --
. | . |   | . | .
3 | . |   | . | .
3 | . |   | . | .
4 | 5 |   | . | .
. | 5 |   | . | .
. | 6 |   | 1 | 1
6 |   |   | . | .
. | . |   | . | .
. | 3 |   | . | .
. | . |   | 0 | .
. | 4 |   | 0 | .
. | . |   | 0 | 0
. | 4 |   | . | 0
3 | 3 |   | . | .
4 | . |   | . | .
4 | 5 |   | . | .
5 | . |   | . | .
6 | . |   | 1 | 1
5 | 6 |   | . | 1
. | 6 |   | . | 1

kitlaan, 2021-12-26:
Did some more reading on how the raspi deals with SPI.

Through the Linux Device Tree Overlay mechanism, the the GPIO+drivers are configured to deal with hardware.  The defaults limit to what the hardware provides for chip selects, but they can be customized to do more.

So in theory, the PCB could be made with one of these configurations (each with their tradeoffs):
1. each SPI w/ N chip selects -- total sampling rate is divided by N (aka as you have today, N=2)
2. M SPIs with N chip selects -- total sampling rate is M/N (aka today you have, M=1, N=2)

Of course we have the hardware limitations:
* raspi type (aka 2 total SPIs vs 4 total SPIs)
* number of available GPIO pins

I'm not sure what design intent you want to go with, but it seems like a reasonable "prebuilt configuration" would be:
* 4 total ADCs using 2x SPI, providing 31 breakers
* this works across all raspis the same way
* since it's a "prebuilt configuration", occupying all the SPIs isn't a downside

Alternatively, what I described a few days back:
* modular 2 ADC board, allowing 15 or 16 breaker config (using the bypass idea)
* the "prebuilt configuration" allows 15 breakers
* someone that wants to deal with the header wiring themselves could get 2-voltage + 30-breakers (or 1-voltage + 31-breakers)
* pro: 2 PCBs should be roughly the same cost as the single 31-breaker PCB
* con: "prebuilt config" only goes to 15
* con: software UI design gets complicated, but the firmware code itself shouldn't be too bad
* pro: possibility of using raspi4 to go up to 4-voltage + 60-breakers (or 1-voltage + 63-breakers)
* pro: possibility of higher sampling rate to use the 2 SPIs in single-adc mode (1-voltage + 7+8-breakers)
* pro: possibility of higher sampling rate using raspi4 to use the 4 SPIs in single-adc mode (1-voltage + 7+8+8+8-breakers)

References:
* [4 SPIs on Raspi4](https://raspberrypi.stackexchange.com/questions/107357/enable-up-to-5-spi-on-raspberry-pi-4)
* [Custom SPI DTB to add CS pins](https://gist.github.com/mcbridejc/d060602e892f6879e7bc8b93aa3f85be)
* [Raspi doc on SPI](https://www.raspberrypi.com/documentation/computers/raspberry-pi.html#spi-overview)
* [mpc3008 spidev C ioctl example](https://gist.github.com/dansimpson/6259253)
* [random: mpc3008 spidev python example](https://tutorials-raspberrypi.com/mcp3008-read-out-analog-signals-on-the-raspberry-pi/)
* [random: spidev nodejs](https://github.com/fivdi/spi-device)

kitlaan, 2021-12-26:
Came up with yet another PCB design idea to allow one board to meet lots of needs. (I think this can handle the 3-phase flow?)

* PCB is laid out for 2x20 header
* ADC<sub>0</sub> is tied to SPI0-CS0
* ADC<sub>1</sub> is tied to SPI1-CS0
* Solder pads allow for a second PCB to daisy-chain SPI0+1's MISO/MOSI/CLK (solder from the pads to the 2nd PCB's header pins)
* Solder pads for SPI0-CS1 and SPI1-CS1 (solder from the pads to the 2nd PCB's CS0 pins)
* Allow solder jumper to enable/disable the voltage pin

Someone that wants to add another chip-select (CS2) would have to solder to PCB<sub>0</sub>'s header pins (bleh), but seems feasible.  (Alternatively, another solder pad to daisy-chain CS2... since SPI1 already has default support for 3 chip-selects... so there would just need to be a custom DTB to add one for SPI0.)

Alternatively, someone that wants to use a different SPI layout entirely would just not use the stacking 2x20 header and manually solder wires to the proper layout.

MarkBryanMilligan, 2022-04-29:
I just migrated from wiringpi to pigpio.  This will allow using the other SPI channels.  Needed a couple changes to pi4j to get it to work, so I'll try to get those submitted next.  I've never contributed to someone else's project before, so gotta go figure that out.

MarkBryanMilligan, 2025-03-16:
This functionality has been released in version 2.0.  Supporting hardware to be released shortly.

Closed 2025-03-16.

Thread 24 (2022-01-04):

I would have loved to back your Kickstarter!

sodabrew, 2022-01-04:
I've had this project starred to watch for updates if you were making a new run of PCBs! Unfortunately, there was no update to the GitHub repo during the Kickstarter campaign to notice via GitHub Notifications that something important was afoot!

Do you have plans to run additional boards? Would you use a platform like Indiegogo to collect post-Kickstarter orders? Would you take a PR to link from the README file in the repo over to the subreddit page to increase discoverability of the community there?

https://www.reddit.com/r/LanternPowerMonitor/

https://www.kickstarter.com/projects/markmilligan/lantern-power-monitor

MarkBryanMilligan, 2022-01-04:
Hi Aaron, sorry about that.  I should have linked reddit to this a long time ago. I pointed reddit to github but not the other way around.  I'll update the readme with the reddit link, but I'll probably leave the kickstarter out since it's all done.

While I'm waiting for parts to come in to fulfill the Kickstarter rewards, I'm setting up an opencart store which will be available from the website ([https://lanternpowermonitor.com](https://lanternpowermonitor.com)).  I've used all of the profits from the kickstarter to order extra inventory and the extra boards and some CTs will be available for purchase sometime in March.

sodabrew, 2022-01-05:
Congrats on this major step in the project!! There's also a lot to be said for not overdoing a Kickstarter.

Closed 2022-02-04.

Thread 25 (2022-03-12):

android app crashes after configure hubs

410sean, 2022-03-12:
after selecting configure hub and granting precise device location permission while using the app, the lantern android app restarts, the next time i select configure hub the app crashes and i see at the bottom app info, close app, or send feedback.

the app continues to crash every time i try configure hub. if i uninstall and reinstall the above repeats.

i am using a samsung s21 ultra 5g

MarkBryanMilligan, 2022-03-12:
Thanks for the report.  I'll try to get a crash log through the google play console.  If you have an option to report it via the device, please do as that may give me a more detailed crash log.  This must be device specific so I'll figure out what's unique to the s21.

MarkBryanMilligan, 2022-03-12:
Ok, turns out this is due to a change in Android 12.  I need to request different permissions for Bluetooth than on Android 7.1 - 11.

I just released version 35 of the app to request those new permissions.  It's in google review now but should be available for download in a few hours.  Thanks for finding this, and sorry for the trouble, I should've caught this in the emulator.

MarkBryanMilligan, 2022-03-12:
It's available in Google Play now, the version displayed is 1.0.20.  Please let me know if it's working now and I'll close this issue.

410sean, 2022-03-12:
the new version no longer crashes at the same spot, the permissions bug and crash is resolved. will try to configure the power monitor now.

Closed 2022-03-12.

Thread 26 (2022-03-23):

Dual pole numbering

zyphlar, 2022-03-23:
Would it be possible to allow for different panel configurations? The default one is typical for US residential panels, but for example my old Pushmatic panel (which needs to be replaced, yes) does its dual pole hookups across the numbers not alongside. So when I want to indicate a 240v circuit the correct spot numbers would be 1-2, instead of the app's assumption of 1&3.

It's not a big deal but it could be a small change that would help especially in other countries or situations where the default layout isn't accurate.

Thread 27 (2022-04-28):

3 Phase Breaker box

LeoLopesLage, 2022-04-28:
Hi Mark. Excellent work!
Would it be possible in future versions of the app to select a 3 phase breaker (3 CTs) in the space type??

My home has 3 phases and, because of that, I have the master breaker with 3 phases. I have an air conditioning system with 3 phases too. I know I can assign 1 CT to each phase and group them, but it would be so much cleaner to have an option with 3 phase breaker (3 CTs).
Thank you.

Leonardo

LeoLopesLage, 2022-08-25:
Thank you!! Just opened 1.1.1 release email. Thanks for the 3 phase update.

LeoLopesLage, 2022-08-25:
Not available in the AppStore yet.

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

MarkBryanMilligan, 2022-08-25:
This GitHub page is for the raspberry pi service code and the web services code.  Version 1.1.1 refers to the raspberry pi service version.  The release that I just made allows the hubs to monitor the voltage of one phase and infer the voltage of phases 2 and 3.  I've added the ability to assign which phase each breaker is on to the android app, but I haven't changed the UI of the panel config to look like an EU panel (because there are quite a few styles).

I have a list of things to add to the iOS app, 3-phase config being one of them, along with billing plan config and a couple bug fixes.  I started a new day job a couple months ago, so I've been spread pretty thin lately.  It's coming though, I appreciate your patience.

LeoLopesLage, 2022-08-26:
Thank you! Nicely done so far... And you always answer the questions or comments. Impressive!

Closed 2022-08-25.

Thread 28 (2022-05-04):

iOS app crashed while adding new Hub

poisa, 2022-05-04:
I'm adding a new hub and all goes as planned while adding the WIFI credentials. At that point it says that the Pi will restart but when it does, the app thinks this is a new hub and asks me to cancel, replace, or expand (I'm not sure what the last option is though). I first clicked Cancel and the app crashed. I then the app would not detect the hub anymore (and it wasn't listed anywhere). I rebooted the Pi and the process started again but tried "replace" this time. It crashed again. I sometimes see the hub and sometimes I don't, however I can reproduce the crashes consistently in the Hubs page.

Thanks for making the iOS app. It looks really promising! Can't wait to test my new monitor.

MarkBryanMilligan, 2022-05-04:
When you're adding a hub for the first time, it should just ask you if you want to add it.  It should only be asking if you want to replace or expand if you already have a hub in your configuration (the expand option is to add a second, third, etc hub to your system if you need to monitor more than 15 breakers).  Did you add a hub previously using the android app?  If you already had it up and running on android, you shouldn't need to change the hub configuration at all.

To start from scratch on iOS, the hub will need to be running version 1.0.8 of the hub software.  I shipped all the kickstarter rewards with 1.0.7. You can download version 1.0.8 with this link:
https://cf.lanternpowermonitor.com/hub_1.0.8.zip
You'll need to take the SD card out of the hub and flash it with this new version using balena etcher (or an sd imaging software of your choice)

Regardless of what version of software the hub was running, or whether the hub had already been added via android, the iOS app shouldn't be crashing.  I'll admit, in my rush to get it released, I didn't test the scenario of connecting to a hub running 1.0.7 that had been previously configured with android.  While you're updating your hub software to 1.0.8, I'll try to replicate that scenario and see if I can get a fix released for the iOS app.  Thanks for letting me know!

MarkBryanMilligan, 2022-05-04:
I also just noticed that you purchased two kits.  To keep things simple, I would try adopting one hub at a time (keep the second hub turned off until you adopt the first).  That's not technically necessary, but it can be a little hard to keep track of which hub you're adding otherwise.

MarkBryanMilligan, 2022-05-05:
No, you can be logged into as many devices as you want, and switching from android to iOS even during setup shouldn't be a problem, it just ended up in a state that I didn't handle very well.  Thanks for finding this scenario, I'll get it handled in the next release of iOS and it'll save a lot of other people from experiencing the same headache!

poisa, 2022-05-05:
Sounds good. You're welcome!

MarkBryanMilligan, 2022-06-16:
Resolved in 1.0.9 of the iOS app.  (I forgot to close this back when I fixed it)

Closed 2022-06-16.

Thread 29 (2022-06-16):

Bypass (decoupling) capacitors for ADC

LukeSkaff, 2022-06-16:
This is a cool project and excited to try it out, thanks for all your hard word.  I noticed the PCB design does not have bypass capacitors (decoupling capacitors) which is standard practice. This will help the noise floor of the design.  You can also read page 4 of the ADC design guide which discusses this.  https://ww1.microchip.com/downloads/en/Appnotes/00688b.pdf

I also noticed there are not individual filtering capacitors to ground for the current transformers inputs which are on other designs, was a benefit not seen from these?

MarkBryanMilligan, 2022-06-16:
There are basically two halves to the pcb, one for doing the voltage monitoring and one for doing the current monitoring.

The voltage monitoring half is run off the 5V rail from the raspberry pi.  That 5V is run through a 68kΩ resistor and then a 33kΩ resistor before going to ground.  That makes the midpoint ~1.63V which puts the AC signal from the 12VAC transformer close enough to the middle of the 3.3V range of the ADC.  That 1.63V DC offset voltage does have a 10uF decoupling capacitor to ground.  So I'm pretty confident that the voltage monitoring side of the board is in good shape.

The current monitoring side is run off of the 3.3V regulated rail of the Pi.  I used the 3.3V rail to run the ADCs and the CT offset because the 3.3V is regulated and regardless of what power supply you use for your Pi, the default CT calibration will be pretty close since the regulator seems to be decent and always gives 3.3V.  I did run that 3.3V directly into the ADCs without any decoupling capacitor because there's not really any other variable load on that side of the board.  The 3.3V signal gets split off to a couple of resistors to get an offset voltage for the CTs, and there is a decoupling capacitor at the midpoint of those resistors.  So that load is very constant and I didn't think I'd need to have a decoupling capacitor after a regulator and before a constant load.  You could try adding one on the 3.3V side of the board right at the power source and see if it makes a difference, but I kind of doubt that it would.

You are correct that I only have one capacitor to ground for all of the CTs.  I didn't think it would make much of a difference and wanted to keep the number of components on the board to a minimum.  The DC offset plane is pretty large and I'd be surprised if adding multiple capacitors to ground would make a difference, but I guess you never know until you try.

I guess the bottom line is, the board is super simple and gives very accurate readings as-is (within 1%), so I figured *shrug* good enough.

KodinLanewave, 2022-07-27:
Realized this probably belongs here instead of in it's own separate issue:

Per the conclusions found in the following analysis for popular CT's:
https://www.casler.org/wordpress/low-current-measurement-performance-of-the-sct013/
Adding a low-value ceramic capacitor on the input of each CT lowers the noise floor significantly; Is it possible to add pad provisions to the PCB for users to add their own filter caps?  0603 provisions seem doable to fit in whatever real-estate is left on the board.
Going a step further, I'd also love a revision of the board where one can modify the ring/shield connections to allow proper grounding of the shield and input from the ring contact for each CT. This would require re-soldering of each CT's connector, however further improve the noise-floor of these devices. Obviously this would mean the wiring is fully incompatible with un-modified CT's, unless there were also headers/jumpers of some kind added to switch input contacts as needed. Just a few thoughts, and something I'd appreciate having the option for.

KodinLanewave, 2022-07-27:
Looking at your PCB files, I'd like to work with your existing schematic; do you have a copy of your schematic design file(s) I might be able to import into kicad for modification?

MarkBryanMilligan, 2022-07-27:
It's in the repo here:
https://github.com/MarkBryanMilligan/LanternPowerMonitor/tree/main/pcb/EasyEDA

I designed it in EasyEDA, but there are format converters out there to get it into kicad.

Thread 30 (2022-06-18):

Multi Phase Solar Systems not calculating correct

tomilein85, 2022-06-18:
I have configured a multiphase (3 1pole Breakers) solar in the app, but only the first is shown in the usage diagram of the day and taken into account for usage calculation.
Of course this is again an issue with european 3 phase systems, but you will have the same issue with multiple solar systems at one place.

MarkBryanMilligan, 2022-06-18:
The only way to monitor 3-phase currently is to put one hub on each phase so that the voltage that is monitored by the 12V input of the hub matches the phase that all of the CTs are on.  (i.e. you need three hubs)  If you use one hub and put CTs on a different phase (solar or otherwise), you might get a reading as the current flow will overlap the out of phase voltage and the aggregated P=IV calculations will give a (very wrong) number.

The way to fix this is to enhance the configuration to allow a way to specify the phase for each breaker.  Then the hub service would need to take the phase into consideration when calculating the power, offsetting the voltage reading by 120 or 240 degrees.  The most time consuming part is the UI enhancement in the app.  Are you using Android?

tomilein85, 2022-06-21:
Hi Mark,

funny thing the main problem solved itself the next day (even if the
numbers are not 100% correct due to phase offset). If you take a look at
these two images, you get the feeling what was going wrong on the 17.
,starting with the 18. everything seems now to be fine (to give a bit of
background information, I have sensors on the mains line to each floor and
the solar is also connected to one of the floors (so possible enhancement
would be to able to subtract the solar from the total usages, but also no
problem if not, since I am going to feed the data via MQTT to openhab and
forward it to the influxdb [so I can do there the math things]).

Thanks

Regards,
Thomas
[image: Screenshot_20220621-055512.png][image:
Screenshot_20220621-055521.png]

MarkBryanMilligan ***@***.***> schrieb am Sa., 18. Juni 2022,
15:33:

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

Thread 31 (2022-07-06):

iOS app won’t graph individual breakers

poisa, 2022-07-06:
Currently the graph only shows if I select “Home”, which in turn selects all the breakers. If I select any other breakers individually or with a multiple selection, the graph doesn’t even render. The only exception is if I select the very first breaker, which renders what looks like the cumulative graph (so this looks like a bug, as well).

poisa, 2022-07-06:
> and then after the config was changed and the hub restarted

Sound like this could be a possibility. I started the system with only a couple of CTs on just to make sure everything was working before I attempted to install the 40 CTs. However, I ran into a snag where I had to remove the hubs and add them again because the app got into a loop and would not let me out of it until I did that. Removing and adding them back on may have cause this issue. But what you say makes sense, so this is more likely something wrong with my initial setup rather than a bug with the app.

> like maybe the headphone jack isn't pushed all the way in

You are absolutely right! Three of the jacks hadn't "clicked" in and I hadn't realized. I noticed something was super odd with some of the CTs but was suspecting I had screwed up the soldering.

Thank you, for the super prompt response. I'm really enjoying the hubs so far :)

Closed 2022-07-06.

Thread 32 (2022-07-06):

iOS billing rates unavailable

poisa, 2022-07-06:
As I was installing the system today, I ran into the Billing Rates section of the docs, but for the life of me can’t find it in the iOS app. This may sound silly but, where is it?

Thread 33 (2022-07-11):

web access to data

410sean, 2022-07-11:
is there a public api or access to data without using an app when hosted at https://lanternpowermonitor.com/ ?

MarkBryanMilligan, 2022-07-11:
You can download all of your raw data (power per breaker per second) at https://lanternpowermonitor.com/console

There is currently no web version of the app itself (graphs and instantaneous power readings).  There will be someday, but it's not high on the priority list right now.

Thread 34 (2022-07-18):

BOM is outdated

zyphlar, 2022-07-18:
There are other 11mm/12mm standoffs for sale on eBay just not with those links. Printed a case, looking great so far!

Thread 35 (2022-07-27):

Provision for filtering caps on CT inputs to PCB

KodinLanewave, 2022-07-27:
Per the conclusions found in the following analysis for popular CT's:
https://www.casler.org/wordpress/low-current-measurement-performance-of-the-sct013/
Adding a low-value ceramic capacitor on the input of each CT lowers the noise floor significantly;  Is it possible to add pad provisions to the PCB for users to add their own filter caps?
Going a step further, I'd also love a revision of the board where one can modify the ring/shield connections to allow proper grounding of the shield and input from the ring contact for each CT.  This would require re-soldering of each CT's connector, however further improve the noise-floor of these devices.  Obviously this would mean the wiring is fully incompatible with un-modified CT's, unless there were also jumpers added to switch inputs as needed.  Just a few thoughts, and something I'd appreciate having the option for.

sodabrew, 2022-07-27:
Filtering caps mentioned in https://github.com/MarkBryanMilligan/LanternPowerMonitor/issues/29 as well, to keep the conversation together

KodinLanewave, 2022-07-27:
Sorry about that, I should probably close this one out and add on to the existing issue.

KodinLanewave, 2022-07-27:
Closing as a duplicate to #29

Closed 2022-07-27.

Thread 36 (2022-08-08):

Breaker list shows breakers that don't exist anymore

poisa, 2022-08-08:
I've renamed some breakers, but the old ones "sometimes" linger in my list of breakers (I haven't been able to figure out when this happens). For example, I have an old one called "Space 7" which I renamed to simply "7" but both appear in the list.
I've reset both hubs several times since I've done this, but the problem persists.

MarkBryanMilligan, 2022-08-08:
I think this bug is in the iOS app, specifically when switching from single pole to double pole, one CT.  For now I cleaned it up in the database.  I'll put this on my todo list for when I go in and add the billing rate config to iOS.

poisa, 2022-08-16:
> when switching from single pole to double pole, one CT

Yeah, that's exactly what happened in my case. Thanks for the prompt response. Looking forward to the new iOS version!

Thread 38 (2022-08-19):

Homeassistant API

zyphlar, 2022-08-19:
Being able to send power data to Homeassistant would be pretty cool! Obviously a "would be nice" feature.

https://www.home-assistant.io/blog/2021/08/04/home-energy-management/

LeoLopesLage, 2022-08-25:
I think it is possible to get this information via https://lanternpowermonitor.com/console

I know that some integrations in home assistant gets their info from a xml.

zyphlar, 2022-08-25:
Hitting a button to generate a monthly data dump which you can then download via another button isn't quite the same thing as an API. Technically possible, but I'd feel bad about doing it to @MarkBryanMilligan 's servers without checking especially when the goal would be near-realtime data.

MarkBryanMilligan, 2022-08-25:
The hubs already support posting data to an MQTT topic.  The problem is that the hubs post the power for every breaker every single second and transforming it from that into something that HomeAssistant can consume will take a little effort.  I put it out there about a year ago hoping that an HA superuser would play around with it, but no one has so far.  Looking at their sensor model I think it would work better if the primary hub pulled down the aggregated per-minute summary (what the phone apps get) and bundle that up into HA's metered format.  It's totally doable, but as someone who doesn't use HomeAssistant, I've been quietly waiting for a HA superuser to speak up and help to tackle the issue.

emersonsc, 2022-11-11:
Why no just give the option to set up MQTT natively? (think Tasmota)

hdoedens, 2022-12-30:
I am using the Lantern Power monitor with Home Assistant.

- Set up the MQTT connection in the config.json on the hub.
- Add the MQTT topic for the breaker data as a sensor to you HA config as a sensor.
- Add a Riemann integration sensor and use the aforementioned sensor(s) as the input for the Riemann integration.

Now you can add the sensor as an energy device to the HA energy dashboard.

zyphlar, 2023-02-25:
OK it took me some extra doing but here's how I got it more or less working (I think:)

- install the the MQTT Broker add-on and enable its integration
- create a user in HA for Lantern, under http://homeassistant.local:8123/config/users
- SSH into your Lantern (pi:LanternPowerMonitor is default) and edit /opt/currentmonitor/config.json, changing the username
and password and url as needed:

```
{
  "host": "https://lanternpowermonitor.com/currentmonitor/",
  "auth_code": "your_auth_code_here",
  "hub": 0,
  "debug": false,
  "connect_timeout": 3000,
  "socket_timeout": 5000,
  "needs_calibration": false,
  "mqtt_voltage_calibration_factor": 0.0,
  "mqtt_port_calibration_factor": 1.0,
  "mqtt_frequency": 60,
  "mqtt_broker_url": "tcp://homeassistant.local:1883",
  "mqtt_user_name": "your_lantern_user_here",
  "mqtt_password": "your_password_here"
}
```

- edit HA's configuration.yaml and add as many breakers as you want:

```
# MQTT
mqtt:
  sensor:
    - name: "Breaker 1"
      state_topic: "lantern_power_monitor/breaker_power/1-1"
      unit_of_measurement: "W"
      value_template: "{{ value_json.power }}"
    - name: "Breaker 2"
      state_topic: "lantern_power_monitor/breaker_power/1-2"
      unit_of_measurement: "W"
      value_template: "{{ value_json.power }}"
```

- Go to Helpers, add a Reimann helper with a unit of Watts and a sensor of the sensor(s) you just added.
- Go to Energy, add a consumption source of that Reimann helper
- Note this will measure in Wh (watt-hours) which is 1/1000 of a kWh.

Rogero54, 2023-03-16:
@zyphlar Thanks for the info, That was all I needed to get the rest of the way to get the data to HA.

zyphlar, 2023-11-17:
@MarkBryanMilligan I think this thread is the only place besides the source where mqtt_broker_url etc are mentioned, do you think you could maybe copy paste some of this at the bottom of the readme for future travelers? The setup is pretty sweet when it works. Any future plans for the project?

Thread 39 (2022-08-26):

Can't get it to work

LeoLopesLage, 2022-08-26:

MarkBryanMilligan, 2022-08-27:
This usually means it failed to connect to your wifi.  There's a bug that I need to fix where the app asks the hub via bluetooth for its account id to make sure it belongs to your account.  Without wifi, the hub can't send the access token to the server to download your config (which contains the account id).  I need to change the app to send the account id separately from the access token so the hub doesn't depend on an internet connection to identify which account the hub belongs to.

So I think the hub has been added to your account just fine, but it's trying to re-adopt the hub because the wifi failed.  If you want to e-mail me at mark.milligan@lanternsoftware.com, let me know which e-mail addresses you created your original account with and I can go grab your old panel config (I'm guessing you may have just switched accounts when you logged back in, there's nothing that would cause your panel to get deleted when logging back in).

LeoLopesLage, 2022-08-29:
Hi Mark.

Thank you. Will e-mail you my original user... But I'm not worry in getting the panel back. I can redo it easy...

What really makes me uncomfortable is the hub in loop. Can't get it to stay connected to my accout...

Today I will try to make another board from scratch... Solder new components. Use a new sd card an flash a new image. I will even try with another pi. Everything new. It must ask for the wifi credentials... I hope it work.

About the board, the CT plugs are connected only with pins 1 (signal) and 2 (VDC), right? (3, 4 and 5 are NC).
And the VDC plug? +12vac is on pin 2 and -12vac on pin 5? (My 12vac font didn't come with p2 plug in it, just the 2 wires)

Thank you.

LeoLopesLage, 2022-08-29:
Hi, replying here too.

This is my email address used to login to Lantern originally.

Thank you

On Sat, 27 Aug 2022 at 18:43 MarkBryanMilligan ***@***.***>
wrote:

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

MarkBryanMilligan, 2022-08-30:
The board is almost certainly not the problem. You should be able to adopt and configure your hub even if there's no PCB attached to the pi.  This is 100% a software issue in the iOS app.

I looked at your account and noticed you're outside the US.  The image is set up for US wifi by default, I know there are settings in raspbian for different wifi standards across the world.  Before you solder another board together (if I'm not too late), I'd recommend hooking up a keyboard and monitor to the pi (if possible) and connecting it to wifi using raspi-config.  If you get it on wifi, it should be able to download your config and start posting data.  If you manage to get that working, please let me know.  If the wifi country setting ends up being the problem, I'll need to enhance the app at some point to send the correct wifi setting to the hub based on your timezone.

LeoLopesLage, 2022-08-30:
Ok Mark, will try it latter today. I'll keep you updated. Thank you.

LeoLopesLage, 2022-08-30:
Mark, it worked. I had to change in raspi-config the WLAN country.
Then, I entered the wifi credentials and rebooted. It connected. Did a scan for hub in the ios app and found Hub1. Rebooted once again. And now it stays connected to the app. No more loops.

LeoLopesLage, 2022-08-30:
Tried to calibrate the hub and get some readings now... Didn't get nothing.
The Hub voltage shows 0.0V unchanged.
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

Can you confirm the pins for +12vac and -12vac?

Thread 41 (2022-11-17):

Reading hub details stalls.  daemon.log shows IllegalMonitorStateException

KevinBenjamin, 2022-11-17:
I am running your image on a CM4, and I can't get the app to connect with it.  When I go to Configure Hubs, it says scanning for hubs, then quickly goes to reading hub details, then back to scanning for hubs.
I noticed these lines that seem to get logged on startup:
```
Nov 17 16:40:03 energy java[595]: Exception in thread "main" java.lang.IllegalMonitorStateException
Nov 17 16:40:03 energy java[595]: #011at java.base/java.lang.Object.wait(Native Method)
Nov 17 16:40:03 energy java[595]: #011at java.base/java.lang.Object.wait(Object.java:328)
Nov 17 16:40:03 energy java[595]: #011at com.lanternsoftware.currentmonitor.MonitorApp.main(MonitorApp.java:305)
```

MarkBryanMilligan, 2022-11-17:
Interesting... I definitely am not synchronizing around that wait call, I kind of wonder how that was ever working.  I'll check in a fix and get a new version released for you.

Unfortunately, I doubt this is the cause of your problem.  Something is probably going wrong elsewhere in the bluetooth handshake that is making the app exit (and then this error happens on an unexpected exit).

I just recently got a CM4 myself after a year of waiting but I haven't had a chance to play with it yet.  I'll see if I can recreate it with mine.

One question, is your phone by chance a Samsung device?

KevinBenjamin, 2022-11-17:
Hi Mark.  My phone is a Pixel 6.
I tried turning off my phone bluetooth and starting the pi, and it creates the same log entries.

MarkBryanMilligan, 2022-11-17:
New version here:
https://lanternpowermonitor.com/currentmonitor/update/lantern-currentmonitor.jar
You can overwrite the one in /opt/currentmonitor on your CM4 and give it a try.

KevinBenjamin, 2022-11-18:
Thanks for the quick response Mark.
I put in the new jar and the daemon.log didn't show the same entries.  However, the app still did the same thing and I found these lines in /opt/currentmonitor/log/log.txt:
`2022-11-18 10:15:02,388 ERROR BleAdvertisement - Failed to unregister advertisement
org.freedesktop.dbus.errors.NoReply: Message recipient disconnected from message bus without replying
	at java.base/jdk.internal.reflect.NativeConstructorAccessorImpl.newInstance0(Native Method)
	at java.base/jdk.internal.reflect.NativeConstructorAccessorImpl.newInstance(NativeConstructorAccessorImpl.java:62)
	at java.base/jdk.internal.reflect.DelegatingConstructorAccessorImpl.newInstance(DelegatingConstructorAccessorImpl.java:45)
	at java.base/java.lang.reflect.Constructor.newInstance(Constructor.java:490)
	at org.freedesktop.dbus.errors.Error.getException(Error.java:157)
	at org.freedesktop.dbus.errors.Error.throwException(Error.java:187)
	at org.freedesktop.dbus.RemoteInvocationHandler.executeRemoteMethod(RemoteInvocationHandler.java:164)
	at org.freedesktop.dbus.RemoteInvocationHandler.invoke(RemoteInvocationHandler.java:228)
	at com.sun.proxy.$Proxy25.UnregisterAdvertisement(Unknown Source)
	at com.lanternsoftware.currentmonitor.bluetooth.BleAdvertisement.stop(BleAdvertisement.java:44)
	at com.lanternsoftware.currentmonitor.bluetooth.BleApplication.stop(BleApplication.java:72)
	at com.lanternsoftware.currentmonitor.BluetoothConfig.stop(BluetoothConfig.java:31)
	at com.lanternsoftware.currentmonitor.MonitorApp.lambda$main$0(MonitorApp.java:300)
	at java.base/java.lang.Thread.run(Thread.java:829)
2022-11-18 10:15:02,439 ERROR BleApplication - Failed to unregister application
org.freedesktop.dbus.exceptions.DBusExecutionException: Refusing activation, D-Bus is shutting down.
	at java.base/jdk.internal.reflect.NativeConstructorAccessorImpl.newInstance0(Native Method)
	at java.base/jdk.internal.reflect.NativeConstructorAccessorImpl.newInstance(NativeConstructorAccessorImpl.java:62)
	at java.base/jdk.internal.reflect.DelegatingConstructorAccessorImpl.newInstance(DelegatingConstructorAccessorImpl.java:45)
	at java.base/java.lang.reflect.Constructor.newInstance(Constructor.java:490)
	at org.freedesktop.dbus.errors.Error.getException(Error.java:157)
	at org.freedesktop.dbus.errors.Error.throwException(Error.java:187)
	at org.freedesktop.dbus.RemoteInvocationHandler.executeRemoteMethod(RemoteInvocationHandler.java:164)
	at org.freedesktop.dbus.RemoteInvocationHandler.invoke(RemoteInvocationHandler.java:228)
	at com.sun.proxy.$Proxy24.UnregisterApplication(Unknown Source)
	at com.lanternsoftware.currentmonitor.bluetooth.BleApplication.stop(BleApplication.java:73)
	at com.lanternsoftware.currentmonitor.BluetoothConfig.stop(BluetoothConfig.java:31)
	at com.lanternsoftware.currentmonitor.MonitorApp.lambda$main$0(MonitorApp.java:300)
	at java.base/java.lang.Thread.run(Thread.java:829)
2022-11-18 10:15:04,463 INFO  PIGPIO - library size: 13520
2022-11-18 10:15:04,473 INFO  CurrentMonitor - Power Monitor Service Stopped
2022-11-18 10:15:32,618 INFO  MonitorApp - Current Version: 1.1.3`

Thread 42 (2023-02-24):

Issue with bluetooth

beamsjr, 2023-02-24:
When installing image 1.1.1 I was not able to connect to the hub.  I connected into the pi and did `sudo systemctl status bluetooth` which gave me

`May 04 23:02:47 raspberrypi systemd[1]: Starting Bluetooth service...
May 04 23:02:47 raspberrypi bluetoothd[577]: Bluetooth daemon 5.55
May 04 23:02:47 raspberrypi systemd[1]: Started Bluetooth service.
May 04 23:02:47 raspberrypi bluetoothd[577]: Starting SDP server
May 04 23:02:47 raspberrypi bluetoothd[577]: Bluetooth management interface 1.21 initialized
May 04 23:02:47 raspberrypi bluetoothd[577]: profiles/sap/server.c:sap_server_register() Sap driver initialization fail>
May 04 23:02:47 raspberrypi bluetoothd[577]: sap-server: Operation not permitted (1)
May 04 23:02:47 raspberrypi bluetoothd[577]: Failed to set privacy: Rejected (0x0b)
May 04 23:04:28 raspberrypi bluetoothd[577]: src/device.c:load_gatt_db() No cache for 57:EA:B1:E1:12:5C

I took the following steps to get it to work, not sure if all were necessary or not.

added pi user to the bluetooth group
'
sudo usermod -G bluetooth -a pi
'
open
'sudo nano /etc/systemd/system/bluetooth.target.wants/bluetooth.service'
Change:
`
ExecStart=/usr/lib/bluetooth/bluetoothd
`
To
`
ExecStart=/usr/lib/bluetooth/bluetoothd --noplugin=sap
`
Then restart
`
$ sudo shutdown -r now
`

Hopefully this helps someone else that has this issue.

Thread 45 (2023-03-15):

I keep losing data because the hubs just stop working until I reboot them

poisa, 2023-03-15:
This has happened several times now and I'm not sure why. For no apparent reason the hubs stop gathering data and the only way to have them start again is to power cycle them. There is no indication that anything is wrong; I just noticed this when the app was showing a blank page. It sucks because I don't check this too often and I only realize after losing several days of data.

I'm using v1.1.1 and just realized that there is a new one v1.1.3, though by looking at the commit messages I don't think these version addresses such a problem.

Rogero54, 2023-03-18:
I have it running in a testing setup and mine is looking it's UP address after a couple hours. Testing it now with a USB NIC to rule out hardware issue. Reboot brings it back. Might swap out the top to see if it is hardware or software.

Rogero54, 2023-03-18:
Been watching the LanternPowerMonitor in UptimeKuma and put a watchdog on it so it reboots if it cannot ping my gateway.
Over the last 6 hours, the watchdog has rebooted it 3 times.
11:05
13:08
and 15:09.

Looks like it is roughly every 2 hours.
Guess the good news is that the data is persistent in the service so it dumps it once it comes back on like.  If there is anything I can provide to help you determine if it is a code bug, let me know.

Roger

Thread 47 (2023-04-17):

IOS app is crashing

cyperous, 2023-04-17:
I would love to provide more info than the app crashing, but I can't open it to find out what's causing it. When I open the app, it crashes the moment it opens. I see a vague glimpse of the login, then the main app, and after login, it crashes; not sure what else I can do to provide more info. If you need me to do something, let me know.

I'm experiencing the same issue on my iPhone and iPad running the latest iOS 16.4.1.

MarkBryanMilligan, 2023-04-18:
Please send me an e-mail at mark.milligan@lanternsoftware.com and let me know what email you tied to your Lantern account.  I'll try to recreate your issue.

cyperous, 2023-04-18:
fondest_outdoor.09 [at] icloud.com

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

MarkBryanMilligan, 2023-04-18:
I can't recreate a crash.  I see it log in and then go to a screen for today which has no data.  It looks like your hub hasn't been posting data since last night around 10:30 pm.  Is the app actually crashing or is it just an empty screen with no data?

cyperous, 2023-04-18:
It doesn't appear to be crashing today; I reset the hub authentication yesterday and thought that was it; at the time, the app was still crashing.

I'll watch it and let you know if anything changes.

I'll update my review on the app store to remove my 1-star.  Honestly, this kind of app is incredible when it works.

Thanks for your hard work.

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

cyperous, 2023-04-20:
It's crashing again, I tapped on the icon to navigate back to the previous day 17th to the 16th, and it crashed. I'm assuming there is no data for April 16th hence why the app crashed. The problem is I can't get back into the app without it crashing instantly.

The app is not optimized and is prone to crashes; any suggestions on keeping it from crashing would be greatly appreciated.

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

aedocw, 2023-08-26:
I'm having the same problem on iOS. Even uninstalling the app completely and re-installing just gives me a flash of the available breakers, and then it quits. I would have thought deleting the app would clear the credentials and allow me to log in again and hopefully reset things, but the credentials must be cached somewhere and I have no idea how to clear them.

The account I'm using is under the email doc@aedo.net. I had previously been using a google account (aedocw@gmail.com) which I will switch back to if I ever figure out how to reset the credentials on my phone.

aedocw, 2023-09-04:
This issue is now resolved for me with the release of v1.0.13.

Closed 2025-05-21.

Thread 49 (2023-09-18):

Double pole breaker / one ct

mdg78, 2023-09-18:
Hello,

It does not appear that the Double Pole (240V) One CT Doubled function is working for me. I have this configured for an oven and a central AC compressor and I am only seeing half the load on the app.

mdg78, 2024-01-19:
I tried deleting that slot assignment and re-adding it and it ended up resolving itself shortly afterwards. I can't remember how long but in a day or two it was working correctly.

paul-ohara, 2024-01-19:
Thanks for the response! I'll give that a shot.

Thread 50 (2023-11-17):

SD card download link broken

zyphlar, 2023-11-17:
Cloudflare is currently giving an error when downloading, but archive.org has it: https://web.archive.org/web/20221226174130/https://cf.lanternpowermonitor.com/hub_1.1.1.zip

Thanks for all that you do, I love this project and hope to see it continue!

MarkBryanMilligan, 2023-11-17:
Oops, yeah I let the SSL certificate expire on the apache box that's behind all of that.  I just updated it and changed the link to the most recent version https://cf.lanternpowermonitor.com/hub_1.1.3.zip

Thanks for letting me know that was down!

Closed 2023-11-17.

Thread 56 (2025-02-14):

make this work with pi zero w

shanelecuyer, 2025-02-14:
is there a way to modify the hub image to work with my pi zero w? i know it uses a different cpu but i dont know enough about these devices to make it boot. i tried adding a dtb file to the boot folder and it didnt work

MarkBryanMilligan, 2025-02-15:
The pi zero w would require a 32 bit image, the ones I have out there are 64 bit.

It's technically possible to run on a zero, but because it's a single core device, you wouldn't get a very accurate reading.  As the thread that monitors the CTs gets interrupted to calculate the power and send the readings to the server, you'd miss samples and get an inaccurate result.

I would recommend getting a zero 2 w with headers soldered on.  It's quad-core and only 20 bucks.
https://www.pishop.us/product/raspberry-pi-zero-2w-with-headers/

Closed 2025-03-16.

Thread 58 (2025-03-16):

Utility rate time of use improvements

shanelecuyer, 2025-03-16:
My electricity provider is Hydro One and I'm on a time of use plan with 3 tiers based on the hour of the day. However, weekends and statutory holidays are all at the low rate. Your app doesn't provide a way to enter this. There are also summer and winter rates with differing hours/rates and this is also hard to enter because I would have to make a new plan for each 6 months for N years

Winter (November 1 to April 30):
Off-Peak: Weekdays from 7 p.m. to 7 a.m., and all day on weekends and holidays.
Mid-Peak: Weekdays from 11 a.m. to 5 p.m.
On-Peak: Weekdays from 7 a.m. to 11 a.m. and 5 p.m. to 7 p.m.

Summer (May 1 to October 31):
Off-Peak: Weekdays from 7 p.m. to 7 a.m., and all day on weekends and holidays.
Mid-Peak: Weekdays from 7 a.m. to 11 a.m. and 5 p.m. to 7 p.m.
On-Peak: Weekdays from 11 a.m. to 5 p.m.

MarkBryanMilligan, 2025-03-16:
The android app allows you to do this.  When you add a rate to your plan, you can put a start and end date for the rate and select recurs annually.  Then also check the 'Applies to Time of Day' box and you can enter start and end times.

Yes, you need to enter many different rates, but I'm not sure how to improve it, you have a complicated billing plan.

shanelecuyer, 2025-03-16:
How can I enter the low rate weekends at statutory days?

MarkBryanMilligan, 2025-04-21:
I released version 49 (1.0.34) of the android app which lets you set day of week for your billing rates.  Not sure how to handle holidays as they're different in every country.

MarkBryanMilligan, 2025-05-21:
@shanelecuyer Any thoughts on this enhancement?  Is it working for you with the exception of holidays?

shanelecuyer, 2025-05-27:
@MarkBryanMilligan i see the changes. I find it a little difficult to setup. Perhaps if the interface was designed to group the time slots under billing rates it would be easier and more intuitive. Billing rate being top tier then the seasonal periods tier 2 and time slots tier 3. Better yet, a visual timedial representation might be beneficial. I've attached a couple images from my utility provider.

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

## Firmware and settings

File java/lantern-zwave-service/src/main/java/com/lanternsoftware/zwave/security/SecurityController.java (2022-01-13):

package com.lanternsoftware.zwave.security;

import com.lanternsoftware.datamodel.zwave.Switch;
import com.lanternsoftware.util.concurrency.ConcurrencyUtils;
import com.pi4j.io.gpio.GpioFactory;
import com.pi4j.io.gpio.GpioPinDigitalInput;
import com.pi4j.io.gpio.PinPullResistance;
import com.pi4j.io.gpio.RaspiPin;
import com.pi4j.io.gpio.event.GpioPinListenerDigital;
import org.slf4j.Logger;
import org.slf4j.LoggerFactory;

import java.util.HashMap;
import java.util.Map;
import java.util.concurrent.ExecutorService;
import java.util.concurrent.Executors;

public class SecurityController {
	protected static final Logger LOG = LoggerFactory.getLogger(SecurityController.class);

	private final Map<Integer, GpioPinDigitalInput> pins = new HashMap<>();
	private final Map<Integer, Boolean> pinEvents = new HashMap<>();
	private final ExecutorService executor = Executors.newFixedThreadPool(2);
	private int eventIdx = 0;

	public boolean isOpen(int _pin) {
		GpioPinDigitalInput pin = getPin(_pin);
		return (pin == null) || pin.getState().isHigh();
	}

	public void listen(Switch _sw, SecurityListener _listener) {
		GpioPinDigitalInput pin = getPin(_sw.getGpioPin());
		if (pin != null)
			pin.addListener((GpioPinListenerDigital) _event -> {
				synchronized (pinEvents) {
					eventIdx++;
					LOG.info("state change from gpio, event {} pin {} to {}", eventIdx, _sw.getGpioPin(), _event.getState().isHigh());
					pinEvents.put(_sw.getGpioPin(), _event.getState().isHigh());
				}
				executor.submit(()->{
					ConcurrencyUtils.sleep(500);
					Boolean high;
					synchronized (pinEvents) {
						high = pinEvents.remove(_sw.getGpioPin());
					}
					LOG.info("handling event {} pin {} most recent event is {}", eventIdx, _sw.getGpioPin(), high);
					if (high == null)
						return;
					_listener.onStateChanged(_sw.getNodeId(), pin.isHigh());
				});
			});
	}

	private GpioPinDigitalInput getPin(int _pin) {
		GpioPinDigitalInput pin = pins.get(_pin);
		if (pin == null) {
			pin = GpioFactory.getInstance().provisionDigitalInputPin(RaspiPin.getPinByAddress(_pin), "SecuritySensor", PinPullResistance.PULL_UP);
			if (pin != null)
				pins.put(_pin, pin);
			else {
				LOG.error("Failed to get pin {}", _pin);
				return null;
			}
		}
		return pin;
	}

	public void shutdown() {
		for (GpioPinDigitalInput pin : pins.values()) {
			pin.removeAllListeners();
		}
		pins.clear();
		executor.shutdownNow();
		GpioFactory.getInstance().shutdown();
	}
}

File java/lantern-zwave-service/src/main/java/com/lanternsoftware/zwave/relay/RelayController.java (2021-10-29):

package com.lanternsoftware.zwave.relay;

import com.pi4j.io.gpio.GpioFactory;
import com.pi4j.io.gpio.GpioPinDigitalOutput;
import com.pi4j.io.gpio.PinState;
import com.pi4j.io.gpio.RaspiPin;
import org.slf4j.Logger;
import org.slf4j.LoggerFactory;

import java.util.HashMap;
import java.util.Map;

public class RelayController {
	protected static final Logger LOG = LoggerFactory.getLogger(RelayController.class);

	private final Map<Integer, GpioPinDigitalOutput> pins = new HashMap<>();

	public void setRelay(int _pin, boolean _on) {
		GpioPinDigitalOutput pin = pins.get(_pin);
		if (pin == null) {
			pin = GpioFactory.getInstance().provisionDigitalOutputPin(RaspiPin.getPinByAddress(_pin), "Relay", PinState.LOW);
			if (pin != null)
				pins.put(_pin, pin);
			else {
				LOG.error("Failed to get pin {}", _pin);
				return;
			}
		}
		LOG.info("Setting pin {} to {}", _pin, _on);
		if (_on)
			pin.high();
		else
			pin.low();
	}

	public void shutdown() {
		GpioFactory.getInstance().shutdown();
	}
}

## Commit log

2021-01-15 Add the case models
    [LPM_Case.blend, LPM_Case.stl, LPM_Case_Lid.blend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]
2021-01-15 Added the pcb files.
    [Gerber_BoardOutline.GKO, Gerber_BottomLayer.GBL, Gerber_BottomSilkLayer.GBO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]
2021-01-21 Set up the hubs to auto-calibrate voltage to a target automatically on first startup to alleviate the need for manual calibration.
2021-01-24 Allow calibration of all ports on a hub at once in addition to individually.
2021-01-29 Add BOM generation from within the app.
2021-01-30 Allow binary and dimmer switches to be grouped together. Allow a custom host to be sent to the power monitor hubs.
2021-02-12 Add the static single hub BOM.
    [BOM.xlsx]
2021-02-12 Make all of the links actual hyperlinks in excel.
    [BOM.xlsx]
2021-02-20 Don't remove breakers if a hub port hasn't been selected. This is a valid case if someone doesn't have hubs configured yet.
2021-02-22 Support posting power to an MQTT topic for Home Assistant.
2021-02-23 Remove the eclipse signatures from the shaded currentmonitor jar so java doesn't lose its mind when trying to start the service.
2021-02-26 Support using one CT to monitor a double breaker by only monitoring one pole and doubling its power.
2021-03-01 Courtesy of JamesAndrews352, STL files have been corrected so they import into various 3d printing software more easily.
    [LPM_Case.stl, LPM_Case_Lid.stl, LPM_Soldering_Jig.stl]
2021-03-01 Courtesy of JamesAndrews352, added a flanged case STL for the 3A+ that allows surface mounting.
    [LPM_Case_Flange.blend, LPM_Case_Flange.stl]
2021-03-06 Add a case for the pi4.
    [LPM_Case_Lid_pi4.blend, LPM_Case_Lid_pi4.stl, LPM_Case_pi4.blend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]
2021-03-10 Add a 3B+ case.
    [LPM_Case_3A+.blend, LPM_Case_3A+.stl, LPM_Case_3B+.blend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]
2021-06-18 Add flange to 4B case
    [LPM_Case_4B_with_Flange.stl]
2021-06-18 Add flange to 3B+ case
    [LPM_Case_3B+_With_Flange.stl]
2021-06-18 Added Sketchup file
    [LPM_Case_3B+_With_Flange.skp]
2021-06-18 Added 4B case with flange Sketchup file
    [LPM_4B_case_with_flange.skp]
2021-07-02 Password reset functionality, ZWave switch schedule improvement, support zwave controller on pi, support relay switches and security sensors.
    [LPM_Case_Flange_4B.blend, LPM_Case_Flange_4B.stl]
2021-07-19 Make sure the switch states stay in sync across zwave controller nodes. Allow switches to be grouped in a hierarchy.
2021-08-03 Add billing rates and track cost for all energy readings.
2021-08-30 Performance improvement for returning energy summaries from DB. Change the way MQTT values are posted. Add a BOM utf-8 char to the BOM csv, yo dawg, bom.
2021-09-08 Keep track of peak production, peak consumption, peak from grid, and peak to grid values to aid in solar panel and storage sizing.
2021-10-18 Add billing plans so different plans can be compared. Performance enhancements to charge calculations.
2021-10-26 Add rudimentary support for DS18B120 Thermometers, MH-Z19B CO2 Sensors, and ZWave.me controllers.
2021-12-04 Added a case for the Zero 2 W.
    [LPM_Case_Z2_Base.blend, LPM_Case_Z2_Base.stl, LPM_Case_Z2_Base_Flange.blend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]
2022-01-13 Improve 3A+ case, making it easier to take the pi out. Improve the fit of the Z2 case. Make it possible for a hub to reload a config automatically when it changes without being restarted. Prevent the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
    [LPM_Case_Flange_3A+.blend, LPM_Case_Flange_3A+.stl, LPM_Case_Lid_3A+.blend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]
2022-01-30 Allow exporting all data in bson, json, or csv formats.
    [LPM_Case_Z2_Base_Flange.blend, LPM_Case_Z2_Base_Flange.stl]
2022-02-10 Auto-detect frequency on first hub startup. If frequency is 50Hz, assume 230V. (This should work for 95% of cases)
2022-02-12 Update the flanged cases for the 3B and 4B so the screws are recessed.
    [LPM_4B_case_with_flange.skp, LPM_Case_3B+.blend, LPM_Case_3B+_With_Flange.skp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]
2022-03-10 Increase the clearances on the 4B case a little bit so you don't need a rubber mallet to get the Pi in there.
    [LPM_Case_Flange_4B.blend, LPM_Case_Flange_4B.stl, LPM_Case_Lid_4B.blend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]
2022-04-04 Fix a bug that was making it impossible to display billing information in the android app.
    [LPM_Case_3B+.stl, LPM_Case_Flange_3B+.blend, LPM_Case_Flange_3B+.stl]
2022-04-08 Update the open source PCB to have better ground connections.
    [Gerber_BoardOutline.GKO, Gerber_BottomLayer.GBL, Gerber_BottomSilkLayer.GBO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]
2022-04-29 Migrating from from wiringpi to pigpio. This increases the sample rate by a factor of 3 and will allow creation of a board that can monitor over 30 breakers with a single raspberry pi.
    This is based on pi4j 2.0 which is in a beta status. I have fixed a few bugs in a local version of pi4j 2.0 to get it to work but I haven't submitted those changes to pi4j yet.
    This change requires a migration to Java 11 and will *NOT* be backwards compatible. Upgrading to this hub software will require that java 11 and pigpio be installed on the hub. This can be done from an ssh session with the following commands:
    apt-get update
    apt-get install openjdk-11-jre-headless
    apt-get install pigpio
    Alternativ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
2022-08-08 Update the non-flanged 3B+ case.
    [LPM_Case_3B+.blend, LPM_Case_3B+.stl]
2022-08-08 Fix the 3B+ lid size.
    [LPM_Case_Lid_3B+.blend, LPM_Case_Lid_3B+.stl]
2022-08-21 Implement 3-phase voltage logic.
2022-10-22 Update BOM for out of stock parts
    [BOM.xlsx, LCSC_BOM.csv]
2022-11-07 Add config flag for hubs to post to self-hosted server with a self-signed SSL certificate. Support Raspberry Pi 2B by handling missing BLE controller and supporting 32-bit pigpio.
2025-02-25 v2 Initial Commit
    This version renames the entire project from "current monitor" to the more accurate "power monitor" and adds support for a 30 port PCB. The software now identifies which board is connected to the pi at startup. As this is a non-passive change, we're moving to version 2.0.0.
    The final version of v1 is available in the branch "1.1.3".
    Currently the Zero 2 W is the only Pi that has a case ready for the 30 port board. Other cases to come shortly as well as more information on how to get a 30 port board. The original 15 port through-hole board will remain the only open source free to use PCB.
    [LPM_Case_Lid_3A+.blend, LPM_Case_Lid_3A+.stl, mitsubishi_ir_codes.csv]
2025-02-25 v2 Initial Commit (with all the files this time)
    Currently the Zero 2 W is the only Pi that has a case ready for the 30 port board. Other cases to come shortly as well as more information on how to get a 30 port board. Before you ask, the original 15 port through-hole board will remain the only open source free to use PCB.
    To do proper versioning, I've swit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
    [LPM30_Case_Z2_Base_Flange.blend, LPM30_Case_Z2_Base_Flange.stl, LPM30_Case_Z2_Lid.blend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]
2025-04-21 Track voltage over time. Support billing rates per day of week.
2025-04-27 2.0.0 Release
    [LPM30_Case_Z2_Base_Flange.blend, LPM30_Case_Z2_Base_Flange.stl]
2025-04-28 Apply the correct PCB voltage correction factor for the 30 port board. Use nmcli to set wifi credentials instead of wpa_supplicant. This fixes a bug that has existed with changing wifi credentials si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
    [PowerMonitor.java]
